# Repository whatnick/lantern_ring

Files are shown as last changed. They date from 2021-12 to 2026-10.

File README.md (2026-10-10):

# Lantern Ring

**One ring to rule them all, in the light bind them**

## v2 physical hardware

[FreeCAD v2 twist-lock hardware](hardware/v2.0/ring_3d/README.md) provides a keyed
30-degree bayonet PCB/battery cassette, opposite-face CR2032 pogo contacts,
one insulated ground lead and screw-retained battery access. The compact crown
is 24.9 mm across, with the original 11 mm band width at the crest and a **rounded open-bottom
elastic band**. Hollow 40-degree conical shoulder walls brace the crown onto the
band, as the legacy side plates did. The shank tapers to 6 mm at the open tips
with comfort-fit rounded edges, using 2.5% less material than the unbraced band. The crown nests onto the finger arc; its LED-inclusive profile
is **11.42 mm above the finger**. A
[same-scale legacy comparison](hardware/v2.0/ring_3d/generated/legacy-comparison.png)
documents the remaining height/diameter difference. Editable CAD and printable
files are included.
Battery replacement needs no soldering; the direct positive pogo and ground
lead still need three permanent joints. This is an unprinted, electrically unqualified prototype for the
mono-colour PCB, not a certified battery-powered product.
The [elastic-fit study](hardware/v2.0/ring_3d/generated/flex-fit.png) illustrates
a 1 mm expansion target, not a qualified size range; PA12 spring-back, creep
and comfortable fit still require physical testing.

### v2 CAD renders

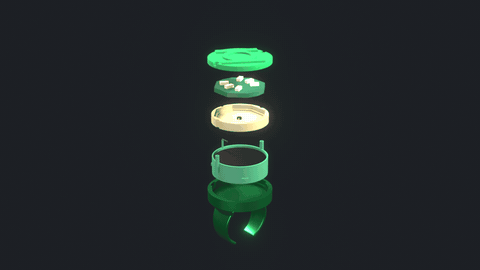
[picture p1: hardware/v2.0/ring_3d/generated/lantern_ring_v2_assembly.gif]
Lantern Ring v2 assembly animation: the exploded cassette drops in under the Green Lantern crown, twist-locks and the LEDs light the crown


Blender 5 assembly animation ([MP4](hardware/v2.0/ring_3d/generated/lantern_ring_v2_assembly.mp4)).

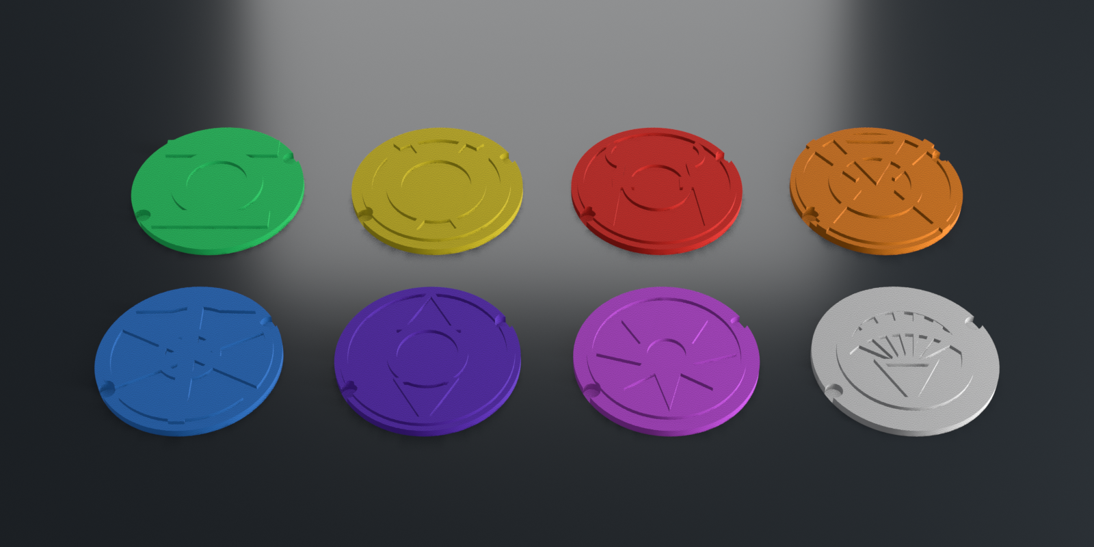
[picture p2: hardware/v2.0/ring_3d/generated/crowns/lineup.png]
Low-profile Lantern Corps crowns: will, fear, rage, avarice, hope, compassion, love and life logos on translucent top pieces


Low-profile [Lantern Corps crowns](hardware/v2.0/ring_3d/README.md#lantern-corps-crowns-low-profile-top-piece):
swappable translucent top pieces that sit 2.3 mm above the PCB (the v1 emblem stood 6.5 mm).

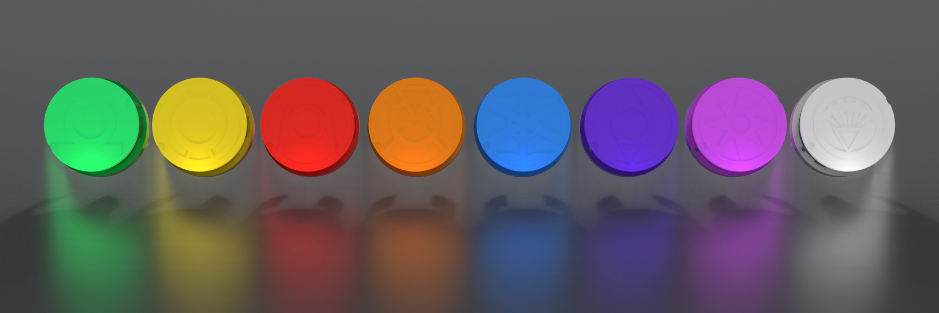
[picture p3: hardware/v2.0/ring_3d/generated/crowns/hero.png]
All eight Lantern Corps rings on their side on a steel surface, glowing caps facing the viewer


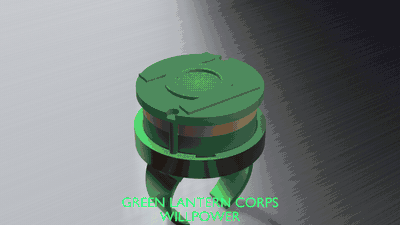
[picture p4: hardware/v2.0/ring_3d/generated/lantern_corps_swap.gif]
Crown swap animation: each Lantern Corps crown is swapped in and the ring relights in that corps colour


Crown swap animation ([MP4](hardware/v2.0/ring_3d/generated/lantern_corps_swap.mp4)),
with each crown and LED colour representing a different Corps.

| Assembled: low crown, braced open tapered band | Exploded: bayonet cassette and pogo stack |
| --- | --- |
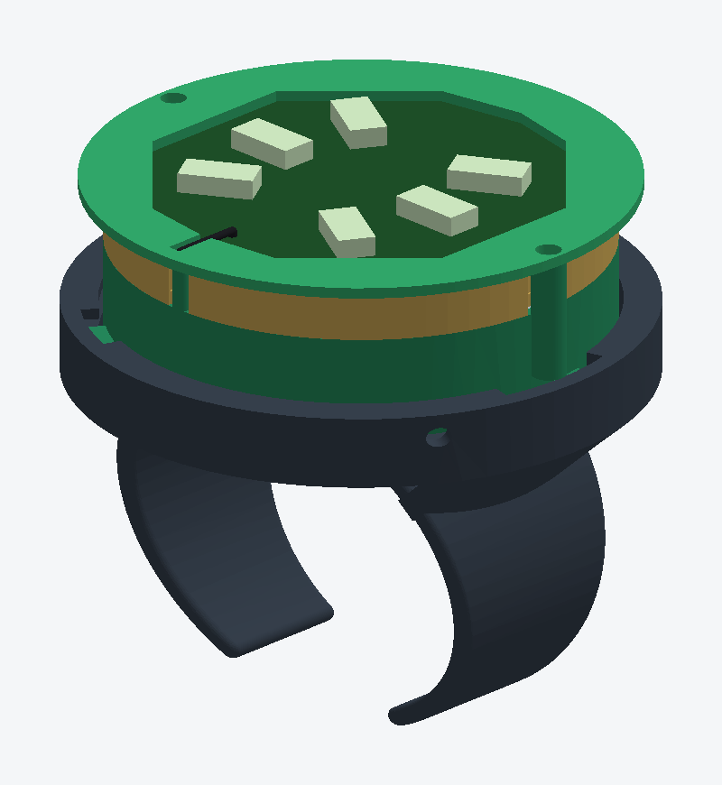
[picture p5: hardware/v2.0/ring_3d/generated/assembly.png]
Lantern Ring v2 assembled CAD with the crown nested on the finger arc and a 60-degree open-bottom band
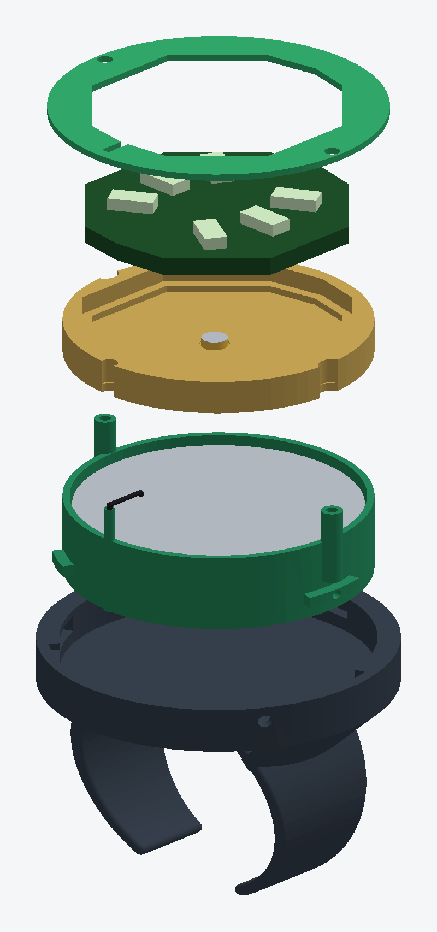
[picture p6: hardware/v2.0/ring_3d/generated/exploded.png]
Lantern Ring v2 exploded CAD showing ring base, CR2032, pogo pins, PCB carrier and bezel
|  |  |

| Same-scale legacy comparison | Open-band elastic-fit screen (unqualified) |
| --- | --- |
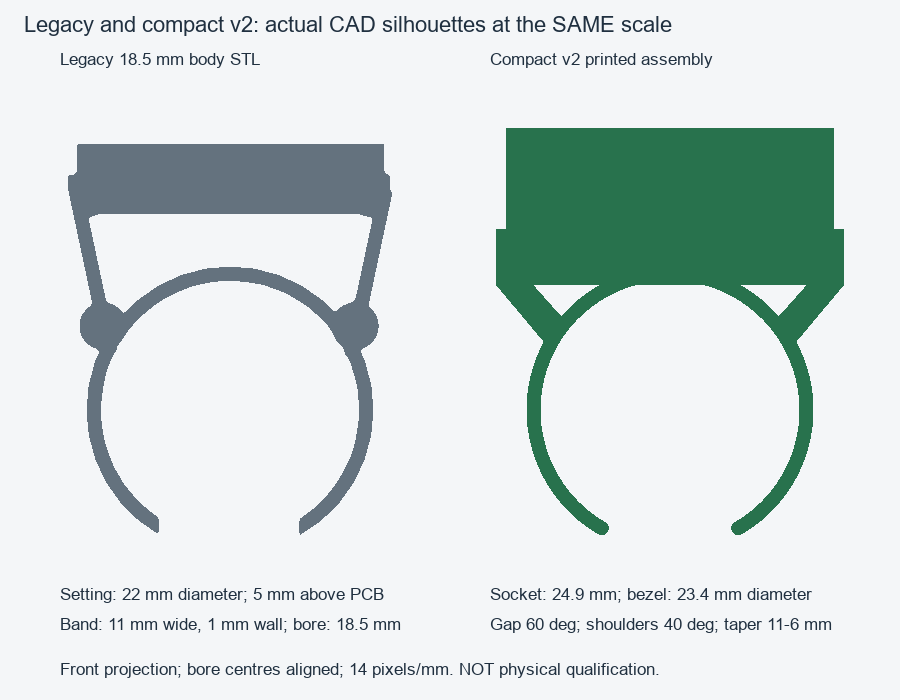
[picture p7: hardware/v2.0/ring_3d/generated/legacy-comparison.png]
Same-scale comparison of the v2 ring against the measured legacy ring
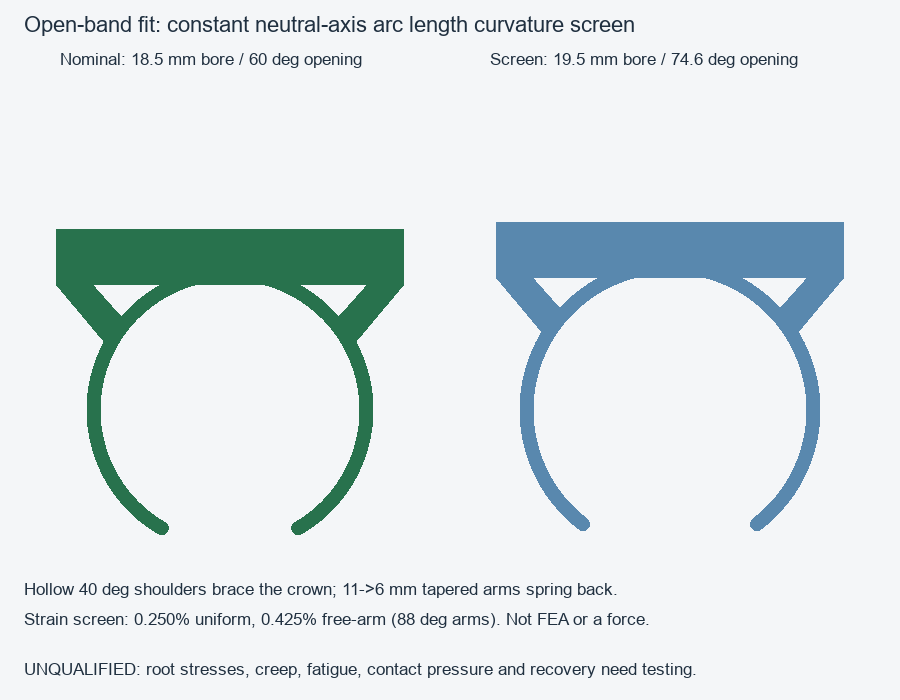
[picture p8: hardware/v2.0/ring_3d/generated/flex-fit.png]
Open-band curvature study from 18.5 mm to 19.5 mm bore
|  |  |

[Repository baseline review](docs/design/repository-review.md) distinguishes the
existing board variants and unfinished experiments.

[Contact and metal-body roadmap](docs/design/contact-roadmap/README.md) explores
copper-tape pressure contacts, replaceable plated springs and an electrically
isolated metal shell, with progressive local renders and prepared Nano Banana
prompts. These concepts do not replace the current manufacturing CAD.

[IR ring programming clip](hardware/v2.0/ring_ir_prog_clip/README.md) is a
solder-free pogo-pin ISP clip for the ATtiny85 `ring_pcb_IR`. It is a probe,
anvil and fence PCB set for an Adafruit 5434-style hinged clip kit. Its pin
spacing comes from the IR board's rear test pads, and it has a standard AVR
ISP-6 header. It passes KiCad ERC/DRC and a FreeCAD virtual fit against
estimated clip dimensions. It has not yet been built or measured.

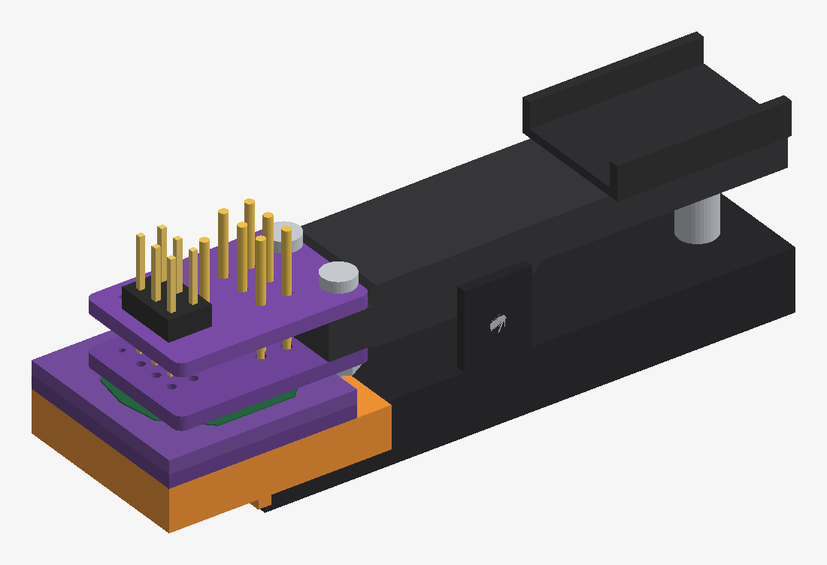
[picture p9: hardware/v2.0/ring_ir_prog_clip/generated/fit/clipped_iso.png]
IR programming clip, virtual FreeCAD fit


Engineering source references and regeneration instructions are in
[development.md](development.md).
| 1. Serviceable pogo | 2. Copper pressure | 3. Plated springs | 4. Floating metal |
| --- | --- | --- | --- |
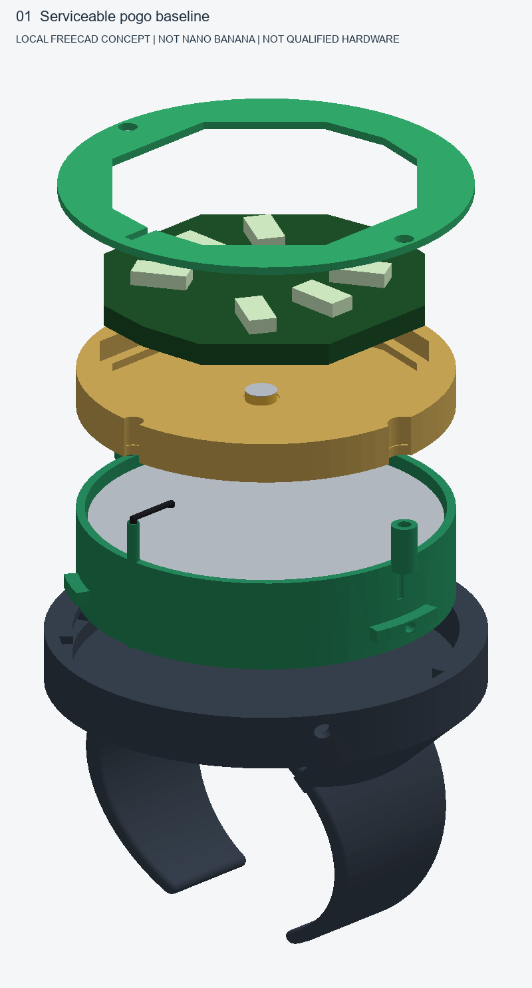
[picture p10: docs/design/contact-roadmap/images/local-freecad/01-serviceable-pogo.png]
Baseline serviceable pogo assembly
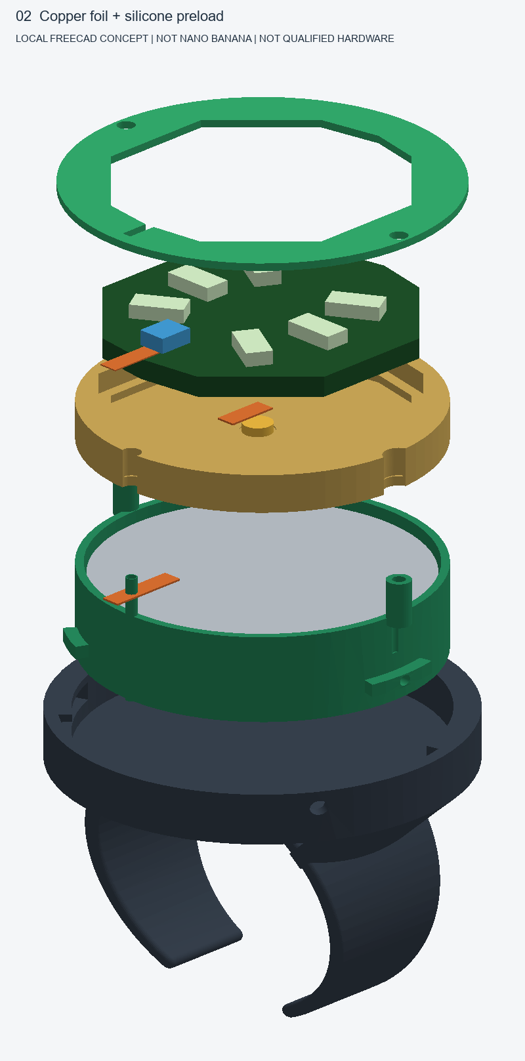
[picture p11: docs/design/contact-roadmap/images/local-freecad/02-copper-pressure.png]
Copper foil and silicone pressure-contact concept
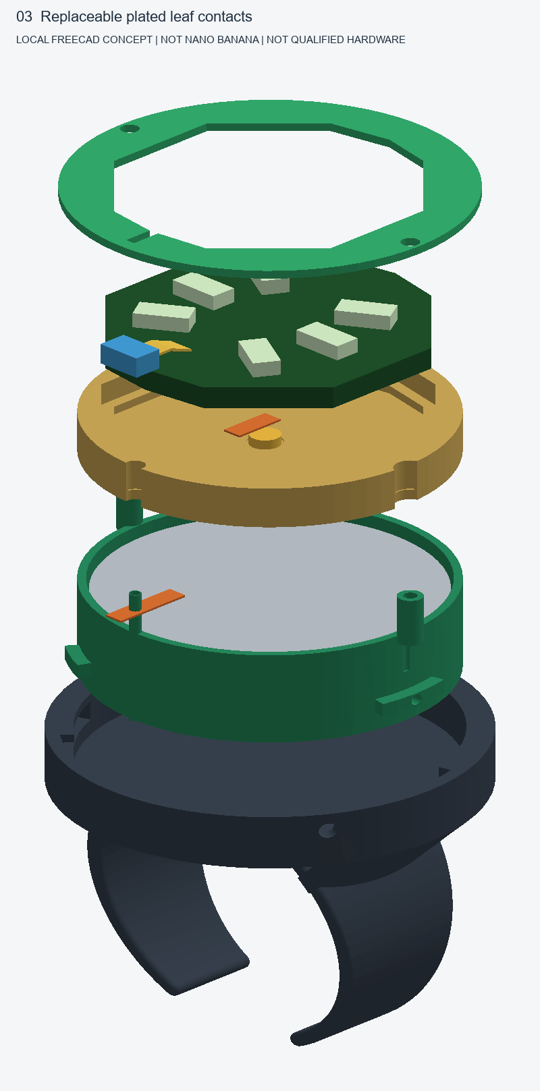
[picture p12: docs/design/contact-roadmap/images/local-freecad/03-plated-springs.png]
Plated spring cartridge concept
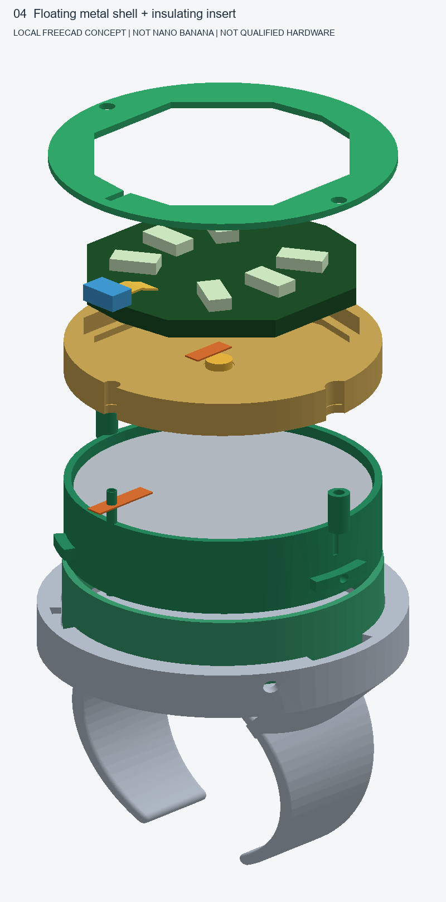
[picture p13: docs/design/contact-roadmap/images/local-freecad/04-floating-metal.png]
Floating metal ring body with polymer insert
|  |  |  |  |

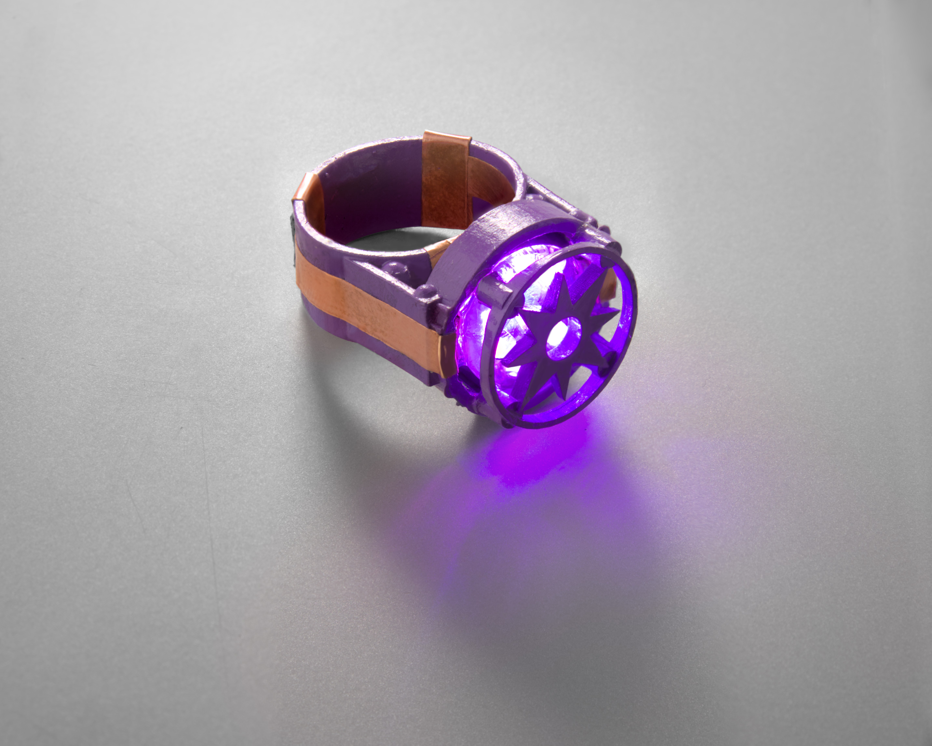
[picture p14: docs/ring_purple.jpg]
Purple Ring

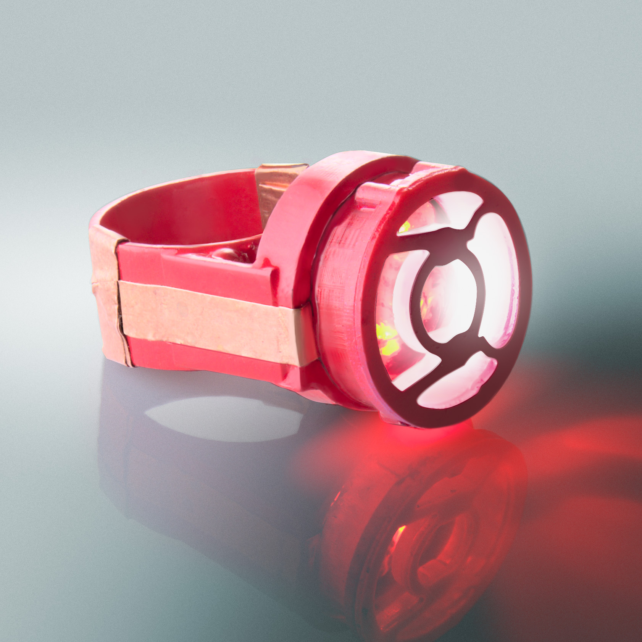
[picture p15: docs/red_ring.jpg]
Red Ring

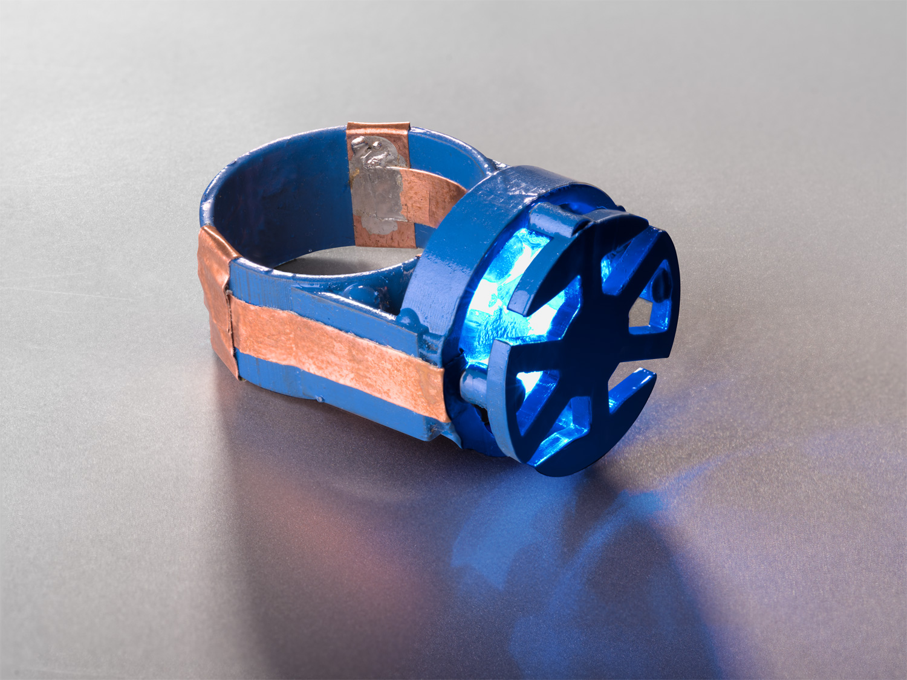
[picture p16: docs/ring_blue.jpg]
Blue Ring


Available on :
- [Tindie](https://www.tindie.com/products/whatnick/lantern-rings/)
- [Etsy](https://www.etsy.com/au/listing/1365896916/lantern-corps-cosplay-ring-with)
- [PCBWay]
- [OSHPark]
- [Aisler](https://aisler.net/p/UOBXJDJP)
- [Shapeway](https://www.shapeways.com/shops/whatnick)
  - [Ring body](https://www.shapeways.com/product/PLQWLUV6V/lantern-ring-body?optionId=251926151&li=shop-inventory)
  - [Green Lantern Logo](https://www.shapeways.com/product/PLQWLUV6V/lantern-ring-body?optionId=251926155&li=shop-inventory)
  - [Yellow Lantern Logo](https://www.shapeways.com/product/87AK6SYQN/yellow-fear-lanterns-logo-from-dc-universe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)
  - [Blue Lantern Logo](https://www.shapeways.com/product/LDGX3RYWW/hope-lanterns-logo-from-dc-universe?optionId=253809602&li=shops)
  - [Indigo Lantern Logo](https://www.shapeways.com/product/RX6YYCM8E/indigo-empathy-logo-from-dc-universe?optionId=253810127&li=shops)
  - [Violet Lantern Logo](https://www.shapeways.com/product/Q4ZM3RG58/purple-love-lanterns-logo?optionId=253810197&li=shops)
  - [Red Lantern Logo](https://www.shapeways.com/product/2T2WC596J/red-rage-lanterns-logo?optionId=253810042&li=shops)
  - [Orange Lantern Logo](https://www.shapeways.com/product/XHF33N3QN/orange-avarice-lanterns-logo?optionId=253810121&li=shops)
  - [Black Lantern Logo](https://www.shapeways.com/product/NEF64B7SB/lantern-ring-life-and-death)
  - [White Lantern Logo](https://www.shapeways.com/product/NEF64B7SB/lantern-ring-life-and-death)
  - [Black MTG Logo](https://www.shapeways.com/product/NJ25J3LPM/magic-the-gathering-black-mana-logo?optionId=253809132)

[LED Colours and quantum physics](https://www.forbes.com/sites/chadorzel/2019/07/01/the-mostly-quantum-physics-of-making-colors/?sh=2ce5846e3953) are inextricably linked.
After watching a temperature based LED colour changing demo at questacon, an idea started forming in my head for using a similar idea with LED's of different colours and seeing how they
react spectrally with temperature.

I have also always been a Green Lantern nerd and I have been making lantern rings since 2010. You will probably find some of them in the wild in Hobart among the clientele of various
pubs and nightclubs. This is a more serious attempt at making a piece of electronic jewellery, cosplay prop and nerdy onanism all rolled into one.

## Licence

[OSHW TAPR](https://tapr.org/the-tapr-open-hardware-license/)

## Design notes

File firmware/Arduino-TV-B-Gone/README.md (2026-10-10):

# Description:  
This code is the TV-B-Gone library ported to run on the Attiny85 back but using the Arduino IDE.  

# README.md update history:  
Readme Last Updated: 22 Oct. 2016  
By Gabriel Staples, http://www.ElectricRCAircraftGuy.com  
-My contact info is available by clicking the "Contact Me" tab at the top of my website.  

# Current Code Version & History:  
See [development.md](development.md) for the source-file history and build notes.

Semver (http://semver.org/) VERSION HISTORY (newest on top):  
(date format: yyyymmdd; ex: 20161022 is 22 Oct. 2016)  
 - 20161022 - v1.3 - Semver versioning implemented; various code updates, clarifications, & comment additions, and changes to fix PROGMEM incompatibilities so it will now compile with latest versions of gcc compiler; also improved blink indicator routines & added the ability to stop the code-sending sequence once it has begun; by Gabriel Staples (http://www.ElectricRCAircraftGuy.com)  
 - 20101023 - v1.2 - Latest version posted by Ken Shirriff on his website here (http://www.righto.com/2010/11/improved-arduino-tv-b-gone.html) (direct download link here: http://arcfn.com/files/arduino-tv-b-gone-1.2.zip)  
 - 20101018 - v1.2 - Universality for EU (European Union) & NA (North America) added by Mitch Altman; sleep mode added by ka1kjz  
 - 2010____ - v1.2 - code ported to Arduino; by Ken Shirriff  
 - 20090816 - v1.2 - for ATtiny85v, by Mitch Altman & Limor Fried (https://www.adafruit.com/), w/some code by Kevin Timmerman & Damien Good  

# Description:  
This code is the TV-B-Gone library ported to run on the Arduino.  

# Background:
See [development.md](development.md) for source-file notes and build details.

Updated code to fix PROGMEM incompatiblities--now works with latest versions of gcc compiler & Arduino IDE
-with other improvements also
By Gabriel Staples (http://www.ElectricRCAircraftGuy.com)

This port to Arduino is by Ken Shirriff.  
For background details on the Arduino port, how to build it, and how to use it, see:  
 * http://www.arcfn.com/2009/12/tv-b-gone-for-arduino.html and here:
 * http://www.righto.com/2010/11/improved-arduino-tv-b-gone.html (newer)

For information on the original TV-B-Gone see:  
http://www.tvbgone.com/. Mitch Altman is the inventor of the original TV-B-Gone.    

The original code is:  
TV-B-Gone Firmware version 1.2  
 for use with ATtiny85v and v1.2 hardware  
 (c) Mitch Altman + Limor Fried 2009  
 Last edits, August 16 2009  

Added universality for EU or NA, and Sleep mode to Ken's Arduino port.  
 -- Mitch Altman  18-Oct-2010  
Thanks to ka1kjz for the code for adding Sleep  
    <http://www.ka1kjz.com/561/adding-sleep-to-tv-b-gone-code/>  

With some code from:  
Kevin Timmerman & Damien Good 7-Dec-07  

# License:  
Distributed under Creative Commons 2.5 -- Attribution & Share Alike  

# CIRCUIT:  
The hardware for this project uses an Arduino:  
 * Connect an IR LED to pin 3 (IRLED).  
 * Connect a visible LED to the pin 13 (or use the built-in LED in many Arduinos).  
 * Connect a push-button between pin 2 (TRIGGER) and ground.  
 * Pin 5 (REGIONSWITCH) must be left floating for North America, or wire it to ground to have it output European codes.  

# User Manual:  
## Background Settings:  
 * The TV-B-Gone for Arduino can use either the EU (European Union) or the NA (North America) database of POWER CODES  
 * EU is for Europe, Middle East, Australia, New Zealand, and some countries in Africa and South America  
 * NA is for North America, Asia, and the rest of the world not covered by EU  
 * Let pin 5 float for NA codes, or wire it to ground to have it send EU codes  
 * Serial debugging output and timing adjustments are configured in the firmware.
  * Fine-tune if necessary  
  * We'd love to have you add more! Just be careful NOT to duplicate codes please!  
  
## Use:  
 * When the device is first powered on, it will quick-flash (30ms on-time followed by 250ms off-time) 3 times if set to output NA (North America) codes, or 6 times for EU (European Union) codes.
 * Once on, the device will enter sleep mode, where it will remain until a button press occurs on the TRIGGER pin, at which point it will wake up and send all of its power codes for the region set according to the state of the REGIONSWITCH pin.  
 * Once you press the TRIGGER button (on pin 2), all power codes will be sent sequentially, one after the other. Note that the trigger button debouncing is done in a very primitive fashion, so quick button presses and releases (<500ms) may work best. If you just hold down the button, the code sending sequence will be continually started, stopped, and started again, since a button press during code sending is used to stop the sending sequence.  
 * After each individual IR power code is sent, a quick flash will occur on the visible LED (30ms on-time) to indicate a code was just sent. Therefore, as the codes are sent, you will see the visible LED flash repeatedly.  
 * Once all codes have been sent (which takes around 60 sec or so), a ~1.3 sec pause followed by 8 quick flashes will occur to indicate that all power codes have been sent. Then, the device will go back into sleep mode until another TRIGGER button press occurs.  
 * Between individual power codes, the TRIGGER button is read one time. If it is read as pressed (LOW), the code sending sequence will be stopped early. This will be indicated by a ~705ms delay followed by 4 quick-flashes, followed by another ~1.3 sec delay to give you time to release the button.  
  * NB: since the TRIGGER button is only read between individual codes, rather than continuously, you may need to hold down the button for a half-second to second or so for it to be read properly as pressed. Once the delay and 4 quick-flashes begin, you can release the button, and the power codes will be stopped. The device will enter back into sleep mode. Press the button again to begin the code sequence again from the beginning.  
  * NB: If you keep holding the button, however, this will be read as a new button-press in the main loop and the sequence will be restarted. Therefore, continually holding the button will just keep starting and stopping and starting again the sending sequence, repeatedly.

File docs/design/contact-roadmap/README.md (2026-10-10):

# Contact and metal-body design roadmap

**Status: ideation, not a revised manufacturing release.** The illustrations
now reference the [compact v2 CAD](../../../hardware/v2.0/ring_3d/README.md):
24.9 mm socket, 23.4 mm bezel, 11 mm-wide open-bottom PA12 band, a nested crown
with an 11.42 mm LED-inclusive above-finger profile, short 0965 SMT pogo pins and a direct
rear-VCC solder connection. They do not reinstate the oversized 36.4 mm crown.
This roadmap explores eliminating the permanent PCB connections while
retaining opposite-face CR2032 pogo contacts and the removable bayonet cassette.
An outer ring body can be metal; the battery/contact insert still needs insulation.
The baseline's split arms use material spring-back; their
[1 mm expansion study](../../../hardware/v2.0/ring_3d/generated/flex-fit.png)
is not a validated fit range. A metal concept must preserve the open-bottom
intent but re-engineer arm thickness, spring force, fatigue and comfort for
its actual alloy/process, not copy the PA12 section.

**Nano Banana generation is blocked:** no authenticated image-generation
service is available, so no Nano Banana images have been generated. The four
renders below were generated **locally with FreeCAD**. They are explicitly
labelled alternatives, not evidence that Nano Banana ran. Development and
image-generation details are in [development.md](development.md).

## Progressive concepts

| Stage | Contact idea | Evidence currently available | Next gate |
| --- | --- | --- | --- |
| 01 | Existing wire loom plus battery pogo pins | Existing native CAD, local exploded illustration | Print/bench qualify the baseline |
| 02 | Copper foil lands, silicone preload, mechanically captured terminations | Local concept overlay and authored contact section | Separate pad-contact coupons and short-circuit checks |
| 03 | Replaceable plated leaf-contact cartridge | Local concept overlay | Engineer force, stops, wiping motion, plating and fatigue |
| 04 | Metal band/socket with floating shell and insulated cassette | Local material/liner concept overlay | Design actual metal process, insulation and isolated fasteners |
| 05 | Contact-path and isolation section | Authored schematic; Nano Banana section prompt prepared | Verify both electrical paths and every possible short path |

### 01 - Serviceable baseline

Baseline serviceable assembly

This is the control design: the PCB rides in a profiled contact deck; a wide-key
three-lug cassette turns 30 degrees counterclockwise and is retained with an
anti-unlock screw. Two battery pogo pins connect through a soldered insulated
ground lead, with the positive pin base soldered directly to rear VCC. Battery
changes need no soldering. The exploded picture is explanatory,
not the literal removal sequence: remove bezel/PCB/deck before lifting the cell.

### 02 - Copper tape and compression pads

Copper foil and silicone pressure-contact concept

Orange lands illustrate copper foil; blue blocks illustrate compliant backing.
Two **separate** PCB contacts replace the PCB wire joints:

- Rear central **VCC**: a copper land faces upward under the exposed pad, with
  compliant backing supported by the insulating deck.
- Front **TP1 `/GND`**: a separate foil land faces downward onto the edge pad,
  with compliant backing supported by the bezel and an insulated perimeter route.

The retaining stack supplies controlled normal pressure. A small seating wipe
may help contact cleanliness; friction alone is not the retention or preload
mechanism. Copper foil is not a spring, and the adhesive side must not be the
pad-contact face. Conductive adhesive at an overlap is not an assumed durable
joint. Capture each continuous strip mechanically, protect cut edges, prevent
foil lift/creep, and keep it away from LEDs and unrelated exposed copper.

The silicone thickness, compression, compression set and final force are **not
specified yet**. The small pad footprint limits contact-placement tolerance.
Prototype removable coupons against the actual board finish before cutting new
carrier tooling. Bare copper oxide, sweat and repeated sliding are reasons to
treat tape as an experiment, not the final wearable contact material.

The conductor-to-pogo interface must also be solved: a captive clamp/spring
socket would replace the SMT base solder joint, but loose tape touching a
pin base is not an acceptable terminal. Four pressure/clamp interfaces are
not automatically more reliable than four permanent solder joints.

### 03 - Replaceable plated spring contacts

Plated spring cartridge concept

Gold-coloured leaf profiles replace the tape contact lands; blue blocks show
mechanical root capture. Separate phosphor-bronze contacts can provide their own
elastic preload, with rounded contact points, designed travel and overtravel
stops. Keep the VCC and ground leaves distinct and provide a replaceable
insulating cartridge rather than springing the PCB itself.

Select alloy temper, thickness, root radius, plating and force against the actual
PCB pad finish. A plated contact rubbing an unsuitable pad finish can still wear
through or become intermittent; "gold coloured" in a render is not a plating
specification. The existing KiCad pads have not been enlarged or changed to hard
gold contact lands. Decide whether a future PCB revision needs larger, same-side
power/ground contact lands before claiming a universal drop-in interface.

### 04 - Metal body, insulated electrical module

Floating metal ring body with polymer insert

The silver shell represents stainless steel or titanium as possible structural/
decorative materials, not selected machining or casting specifications. The
green sleeve shows the intention to keep the electronic cassette isolated.
The contact leaves themselves are conductive metal; they remain separate from
the worn shell.

**Do not manufacture the current polymer RingBase STEP in metal as a direct
material swap.** The local illustration reuses the silhouette and adds a liner
overlay; that liner is not fitted into a redesigned bayonet clearance stack.
Wall thickness, tool access, undercut tracks, fastener threads, finish, mass and
liner retention all need a metal-specific CAD revision.

| Metal configuration | Decision |
| --- | --- |
| Floating metal band/socket + continuous polymer liner + two independent contacts | Preferred development direction: metal carries mechanical loads, not battery current |
| Metal body used as ground return | Deferred research option, not implemented: one conductor may be saved, but positive-cell-case contact, sweat, galvanic corrosion, skin exposure and fault paths become harder to control |
| One-piece metal body used for both poles | Not possible without electrically separated conductive regions; do not bridge VCC and ground |

A metal-body design must include:

- Continuous electrical isolation around the battery **positive case/rim**,
  negative contact, both PCB contacts, PCB edges and every termination.
- Insulating sleeves/washers where screws could reach circuitry, with retained
  insulation that cannot shift when the cassette is serviced.
- A raised insulating rim and clearances that survive wear, impact, debris and
  sweat. Paint, anodizing and tape adhesive are not the sole insulation barrier.
- Accessible contact cartridges, anti-unlock retention, deburred skin-facing
  surfaces and a process/finish appropriate for skin contact.

No minimum clearance, liner thickness, metal alloy or skin compatibility is
qualified here. If metal is intentionally connected to a net in a later study,
document that choice explicitly and reassess every short/fault path; do not
silently treat a conductive shell as "ground".

### 05 - Contact topology and insulation

Authored pressure-contact and metal-isolation diagram

This schematic is manually authored, not an AI image or a dimensioned CAD
section. It shows the **opposite preload directions** needed by the existing
board: upward onto rear VCC, downward onto front TP1 ground. The illustrative
leaf/foil shapes in the local exploded renders have intentional visual gaps;
they are not assembled contact-force or continuity simulations. Some path
segments are omitted to keep the images readable. **The schematic and written
net map, not the visual proximity of surfaces, define the intended circuits.**

## Image review

Any generated concept image must be checked for electrical shorts, correct
cell polarity, shell isolation, contact preload and service access. AI imagery
is not dimensional evidence and must not be used to select dimensions or prove
compliance. The current concept renders are not manufacturing geometry.
Development, prompt and provenance details are in [development.md](development.md).

## Prototype gates before promoting any concept into v2 CAD

1. Use separate contact coupons to measure preload, assembly tolerance and
   serviceability. Establish suitable contact-force limits without bending PCB
   edges or overstressing silicone/leaves; do not copy the battery pogo's force
   specification onto PCB leaf contacts.
2. With no cell fitted, verify each intended contact path and isolation between
   VCC, ground and the floating shell. Check terminal clamps, screw paths and
   contact motion through the complete service/lock range.
3. With a current-limited source and representative load, measure voltage drop
   and interruptions while twisting, tapping and moving the assembly. Define
   resistance and transient limits from the LED circuit budget before testing.
4. Trial repeated insertion, battery replacement, contamination/sweat exposure,
   foil/adhesive creep, leaf fatigue, liner wear, drop and accidental countertwist.
   Recheck isolation and loaded contact performance after each exposure.
5. Resolve the mono board's current-limiting and reverse-insertion risks before
   wearable use. Never solder to or charge a primary CR2032. Screw retention is
   not a claim of battery-compartment certification; keep this adult prototype
   away from children.

Once those gates pass, update parameterised engineering CAD, PCB contact lands
if needed, contact BOM and assembly instructions, and run the native/STEP/STL
and motion checks again. Until then the shipped v2 CAD remains the baseline.

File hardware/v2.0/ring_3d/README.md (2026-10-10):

# Lantern Ring v2: keyed twist-lock hardware

**Prototype, not a physically qualified product.** This design replaces the
monolithic v1 assembly with a removable PCB/battery cassette. It drops in, turns
30 degrees counterclockwise as viewed from above, and locks under three bayonet shelves.
One lug is wider to enforce orientation. The PCB sits in a profiled pocket in the
contact deck; **turn the cassette/bezel, never the PCB**.

Assembled CAD
Exploded CAD

Assembly animation

[Assembly animation MP4](generated/lantern_ring_v2_assembly.mp4): the exploded
stack drops into the carrier, the cassette inserts and twist-locks 30 degrees
under the Green Lantern (willpower) crown, and the LEDs light the crown lens.

Same-scale comparison with the legacy ring

Open-band elastic-fit curvature study

The [contact and metal-body roadmap](../../../docs/design/contact-roadmap/README.md)
explores solderless PCB pressure contacts and a floating metal shell with an
insulating cassette. Those renders are concepts, not replacement manufacturing
geometry or qualified electrical interfaces.

## Files and compatibility

The project includes an editable FreeCAD assembly, STEP reference geometry and
printable STL files. See [development.md](development.md) for source references
and regeneration instructions.

The supported board is the **v2 mono-colour PCB only**:
17.78 x 19.05 mm, 1.6 mm thick, with a ten-vertex asymmetric outline. This is not
the v1 17.78 mm octagon. The generator reads actual Edge.Cuts, pad nets and the
rear mask opening, rather than using a library bounding box that includes the
outline stroke. IR, v1 multi-colour and the unfinished DotStar board need their
own measured contact decks; they are not drop-in electrically compatible.

Default dimensions: **18.5 mm unloaded finger bore, 11 mm band width, 24.9 mm
maximum crown diameter and 11.2204 mm printed crown height above Z=0**.
The LEDs extend to Z=11.7204. The bore apex is raised to Z=0.3, so the true
**LED-inclusive profile above the finger is 11.4204 mm**, versus 12.7204 mm
for the previous closed-band design. Removing surplus negative-contact clearance
and reducing the bezel from 1.2 to 0.6 mm lowers the actual crown; the image
has not just been repositioned or rescaled.
The upper bezel is 23.4 mm across. These replace the oversized 36.4 mm diameter /
22.4 mm stack; neither PCB nor cell has been scaled.
Legacy 15.5/16.5/18.5/19.5 mm bore sizes can be regenerated; the 15.5/16.5 mm
bores need a reduced expansion target to stay within the free-arm strain screen.

### Measured legacy envelope and remaining difference

The legacy ring setting has an 11 mm outer radius and is 5 mm high above the PCB
datum; its 18.5 mm band has a 9.25 mm bore radius, 10.25 mm outer radius and
11 mm width. The compact band restores that **1 mm wall**, too.
The legacy 18.5 mm body STL is approximately 23.14 mm wide and 27.90 mm high.
README photographs corroborate the shallow crown/broad-band proportions, but
are not calibrated rulers. The generator measures these native objects and
records their source hashes; the comparison uses the real legacy mesh and new
printed solids at the **same scale**, with finger-bore centres aligned.

| Measured default 18.5 mm body | Legacy | Compact v2 |
| --- | ---: | ---: |
| Setting / upper bezel diameter | 22 mm | 23.4 mm |
| Maximum body width | ~23.14 mm | 24.9 mm |
| Overall printed-body height | ~27.90 mm | ~29.11 mm |
| Band width / wall | 11 / 1 mm | 11 tapering to 6 / 1 mm |
| Crown-to-band bracing | ~12-17 deg near-vertical plates, hollow | 40 deg hollow conical shoulders |

This is **not an exact 22 mm replacement**: the keyed polymer tracks need a
24.9 mm socket, 2.9 mm wider than the historical setting. The face lip is now
2.2 mm above the PCB underside, rather than 5 mm. Two spring contacts still add
4.4704 mm of working axial height around the unscaled 3.2 mm cell, so the
complete enclosure remains taller than the old direct-contact body. The old
5 mm face height and the new 11.2204 mm base-to-top stack have different datums
and must not be presented as equivalent measurements. Matching the complete
old envelope would require a different contact architecture, not uniform scaling.

### Open-bottom material-spring fit

The closed loop is replaced by **two continuous 1 mm-thick PA12 arms**, with a
60-degree bottom opening and 0.5 mm-radius end caps across the band width.
The unloaded tip gap is 8.75 mm. The top sits low on the circular finger
arc: the raised bore cuts into the crown underside, while a **continuous 0.5 mm
floor separates skin from the contact well**. Only the finger band is open; the
battery compartment is not.

### Braced shoulders and tapered comfort-fit band

Like the legacy body's slanted side plates, **hollow 1 mm conical shoulder walls**
brace the 24.9 mm crown overhang onto the band. Each wall leaves the crown
underside at its 12.45 mm rim and descends **40 degrees from the crown axis**
(validated 30-45 degrees), meeting the band 4.09 mm below the
crown, 61.7 degrees from its crest. The walls lean less steeply than the old
~12-17-degree plates, so they meet the band higher, keeping long free spring
arms. At 50 degrees from horizontal, they print without supports. The
triangular pockets between walls and band remain open front-to-back, saving
material and allowing powder removal.

Following common ring-profile practice (see
[MOH London ring profiles](https://www.mohlondon.com/guidance/design-basics/ring-profiles)),
the shank tapers on its lower side: one plane per side narrows the band from the
legacy **11 mm crest to 6 mm at the open tips**. The long edges are rounded to
a **0.35 mm comfort-fit radius**.
The narrower, lower arms also make bending stress more uniform along the spring.
Net RingBase volume falls from 1194.3 to 1164.8 mm^3 (-2.5%), despite the
added bracing. OCC produces C0-continuity BSpline fillet faces; the validator
accepts only those flags, while every other BOP error, watertight-mesh check
and STEP round trip remains strict.

Elastic bending of these free arms supplies spring-back and fit preload; there
is no additional metal spring or adjustment screw. Start with a nominal bore
close to the measured finger size. A slightly smaller unloaded bore can supply
preload only after fit/force testing; do not force an undersized print onto a
finger or use elastic travel to compensate for a wrong ring size.

The 1.0 mm expansion is a **screening target**, not a certified 18.5-19.5 mm
size range. The illustration preserves neutral-axis arc length while widening
the opening to about 74.6 degrees. The simple curvature estimate
strain = wall/2 * (1/R - 1/(R + expansion/2)), with R = (bore + wall)/2,
gives approximately **0.250%** outer-fibre strain. The shoulders stiffen the
root, so a second screen assumes only the 88.3-degree free arm takes the same
tip rotation: 0.250% x 150 / 88.3 = **0.425% free-arm strain**. Both omit root stress
concentration, contact loads, nonlinear geometry, residual print stresses,
anisotropy, creep and fatigue. It is not FEA or a spring-force prediction.
The 0.5% screen ceiling is a conservative design input, **not a published
PA12 cyclic allowable**.

Use a controlled ductile PA12 process for this spring geometry. The
[EOS PA 2200 material reference](https://store.eos.info/products/pa-2200-polyamide-12)
is a material-selection starting point, not a guarantee of elastic recovery.
Print an actual split-band coupon in the intended build orientation and finish,
cycle it on 18.5/19.0/19.5 mm gauges, and measure force, permanent set and recovery
before a worn trial. Repeat after warm/humid conditioning and sustained
deflection. Stop if the roots whiten/crack, the band takes a set, or fit is
painful/restricts circulation. No claimed skin compatibility or wear safety.
Do not copy the same thickness into resin, PLA or a metal body: their spring
stiffness and failure modes differ. Metal needs separately engineered arms.

## Development

The assembly is parametric and its source, validation, test and regeneration
workflow are documented in [development.md](development.md).

### Assembly animation (Blender 5)

The animation uses the Will (Green Lantern) crown in place of the plain bezel.
Colours are illustrative: the lower body is shown as emerald metal and the
crown as frosted translucent plastic. Intermediate scene files and frames are development artifacts and are not
distributed.

### Lantern Corps crown swap and hero still

Lantern Corps crown swap

[Crown swap MP4](generated/lantern_corps_swap.mp4): on a brushed-steel surface,
each crown lifts off, the light goes dark, the next corps crown drops in and the
LEDs relight in that corps colour, with a caption naming the corps and light.

All eight Lantern Corps rings on their side on steel, caps facing the viewer

Corps ring-body tints are illustrative; only the crowns are generated geometry.

## Lantern Corps crowns (low-profile top piece)

Lantern Corps crown lineup

The v1 emblem stood a 2 mm logo on 5 mm risers: 6.5 mm above the setting.
The replacement **crown** is the validated bezel (same PCB-edge
clamp, M1 x 4 screws and ground-lead relief), a skirt that clears the LEDs by
0.2 mm, a 0.4 mm diffuser lens and a 0.6 mm raised logo. The crown top is
**2.3 mm above the PCB and 1.2 mm above the tallest LED** (12.62 mm profile
above the finger). Each crown is printed in one piece from translucent material
and is swapped by removing the two bezel screws.

Logos are traced from the per-corps sketches in the v1 FreeCAD assembly into
tool-neutral closed even-odd outlines, centred on the ring axis. They are
pre-rotated by the 30-degree lock angle so they read in the v1 orientation once
locked, and clipped to the 23.4 mm bezel.

| Crown | Corps | Light | Volume (mm³) |
| --- | --- | --- | ---: |
| `will` | Green Lantern Corps | willpower | 497 |
| `fear` | Sinestro Corps | fear | 499 |
| `rage` | Red Lantern Corps | rage | 477 |
| `avarice` | Orange Lantern (Agent Orange) | avarice | 509 |
| `hope` | Blue Lantern Corps | hope | 520 |
| `compassion` | Indigo Tribe | compassion | 476 |
| `love` | Star Sapphires | love | 474 |
| `life` | White / Black Lantern | life and death | 491 |

The STEP crowns are supplied in the cassette insertion frame, and the printable
STLs are oriented **logo face down**: the relief prints first and the lens
bridges it. Their geometry and regeneration workflow are documented in
[development.md](development.md).

**Not printed yet.** Lens light spread, 0.6 mm relief legibility and the 2.2 mm
counterbores that notch the crown rim need a test print.

## Printed parts and purchased parts

| Item | Quantity | Specification |
| --- | ---: | --- |
| RingBase | 1 | Braced, tapered comfort-fit split band and nested keyed bayonet socket |
| Carrier | 1 | Insulated battery well, negative pogo seat, lead channel, lugs, side pillars seated on the RingBase |
| ContactDeck | 1 | Positive pogo seat and actual PCB pocket |
| Bezel | 1 | PCB-edge clamp and open optical window |
| Crown (optional) | 1 | Replaces Bezel: translucent Lantern Corps logo top piece, see [crowns](#lantern-corps-crowns-low-profile-top-piece) |
| Spring contact | 2 | Mill-Max **0965-0-15-20-80-14-11-0**, surface mount ([alternatives](../../../docs/design/pogo-pin-comparison.md)) |
| CR2032 | 1 | Primary 3 V cell, nominal 20 x 3.2 mm |
| Insulated flexible wire | 1 | Fine-stranded wire, **jacket OD <=0.4 mm**, black |
| Bezel screw | 2 | M1 x 4 mm plastic-compatible thread, head OD <=2 mm |
| Anti-unlock screw | 1 | M1 x 2 mm plastic-compatible thread, low-profile head |
| Pin-retaining adhesive | Small amount | Nonconductive, electronics-compatible epoxy |

Use a dimensionally controlled PA12 process for the compact parts, not brittle
decorative resin. The battery well has a 0.5 mm wall and the outer track wall is
0.8 mm: this is **not a drop-in coarse FDM print**. Qualify these small walls,
the 1 mm lugs, 0.6 mm bezel and M1 threads on coupons before printing the ring.
RingBase needs appropriate supports under the crown and track
roofs; its Z=0 STL position is not a promise of support-free printing. The deck
and bezel are naturally base-down. Deburr/smooth skin-facing band edges and all
track mouths. Do not paint contact pockets or functional sliding surfaces.

Nominal clearances: 0.20 mm carrier/socket radial, 0.25 mm PCB per edge,
0.15 mm cell radial, 0.20 mm lug/track axial, 2 degrees at
each lug flank. Measure a first print and calibrate for the printer; do not force
an interference fit against the PCB or battery. Ream small holes as necessary.
The carrier's two side pillars extend down to the RingBase top at the socket
shoulder (Z=4.0 mm) and bear on its annular wall. Keep the pillar bottom and
socket top at the same height when changing the stack.
The 1.75 mm barrel bore must remain smaller than the 1.829 mm flange: do not
drill through the retaining shoulder. Epoxy is required to retain the pins under
spring load; printed shoulders alone do not secure both directions. The upper deck rests
on the carrier shoulder; its two side notches clear the external screw towers.

## Electrical interface and soldering

**CR2032 positive (+) face UP.** Positive case/rim belongs to VCC; the inset
negative face points down. Never rely on the rim as a ground contact.

| Circuit path | Physical connection |
| --- | --- |
| Positive | Downward-facing SMT pogo at CAD (0, +0.381) touches the + top face; its base is soldered directly to the rear exposed VCC circle |
| Negative | Upward-facing lower SMT pogo at CAD (0, 0) touches the centre of the inset - bottom face; black lead joins its base to front **TP1 `/GND`** |

CAD XY origin is KiCad (136.906, 83.185) mm. CAD +Y is KiCad -Y, without
mirroring the board. TP1 is CAD (-0.0254, +7.493). The rear exposed VCC circle
has radius 2.962124 mm; it is **not ground**.

The [manufacturer drawing, page 24](https://www.mill-max.com/sites/default/files/external/assets/2020-04/ultra_low_profile_spring_pins_rev._04.14.20.pdf)
specifies 2.54 mm free height, 0.3048 mm mid-stroke, 0.6096 mm full stroke,
1.626 mm barrel, 1.829 mm base, 0.7112 mm base height and 1.067 mm tip.
There is **no projecting solder tail**. The CAD uses a conservative stepped
external envelope (body height = free height minus full stroke), not internal
pin construction. A 0.05 mm solder land models the direct positive PCB joint.
Both tips are nominally compressed 0.3048 mm. The combined budget is
**+/-0.2524 mm**, allowing 0.0524-0.5572 mm compression.
Supplier dimensions and cell tolerances must be checked again for substitutions.

The pin length allowance is the manufacturer's +/-0.006 inch (+/-0.1524 mm).
The other allowances are **requirements**, not assumed printer or CR2032
capabilities: measure/sort cells to +/-0.05 mm and finish/shim the assembled
contact stack to +/-0.05 mm. Ordinary +/-0.2 mm printing/cell allowances would
lose preload or bottom out these short pins. Do not use a build outside those
measured budgets. The first-build qualification must measure each pin's free
height and both actual compressed gaps.

There is **no soldering to the battery** and no solder work for routine battery
replacement. The compact assembly needs **three permanent joints**: upper SMT
pin to rear VCC, black wire to lower pin base, and black wire to TP1. This removes
the red wire and one joint compared with the previous four-joint loom; it is
not a solderless retrofit to the unmodified PCB.

Start with approximately 35-40 mm black lead, then trim during dry assembly.
Leave 8-10 mm black service slack folded in the 3 mm wide underside
channel so the board/deck can lift for cell replacement. The CAD wire shapes are
nominal jacket-routing envelopes, not bend-radius or service-loop simulations.
Use strain relief on insulated wire, never on plungers. Keep solder, epoxy and
flux off spring tips and out of barrels. Insulate the lower base joint. Nothing conductive may bridge
the cell's negative face to its positive case.

## Assembly and service

1. Dry-fit all four prints without a cell. Check the wide key, insertion,
   counterclockwise turn, end stop and anti-unlock screw alignment.
2. Install the lower pogo upward through the Carrier's underside counterbore;
   seat its flange and bond the barrel/flange without contaminating its travel.
   Solder the upper SMT pin base squarely to the PCB's rear VCC land, then
   lower it into the deck counterbore. Its spring points down. Secure its barrel
   to the deck without loading the solder pad in service. Let adhesive cure fully.
3. Build/fit the black lead, with the battery absent. Connect it to
   front TP1 `/GND` and the lower SMT base. Check continuity from
   each tip to its intended pad and absence of a VCC/GND short.
4. Insert the cell **+ up**, lower the deck into the open carrier, and seat the
   PCB component-side up with TP1 aligned to the ground-wire relief. Keep slack in the underside
   channel and route black through the bezel's ground-pad relief.
5. Fit the bezel and two M1 x 4 screws into the carrier towers; tighten
   gently, without bending the PCB or stripping the plastic. They retain both
   PCB and deck. Check that the leads are not pinched.
6. Align the wide lug with its wide slot, lower the cassette until seated,
   turn counterclockwise 30 degrees, then install the M1 x 2 anti-unlock screw through
   the radial crown hole into the wide lug's pilot. **The screw is mandatory**:
   friction alone is not an anti-rotation latch.

The **cassette** has positive orientation keying (24/14/14-degree lugs), not the
bare PCB: printing clearance can accommodate a 180-degree reversed board in the
profiled pocket. Align TP1 to the bezel relief and verify the contact loom;
do not rely on the PCB outline alone to establish electrical orientation.

To replace the cell, remove the anti-unlock screw, turn the cassette back
30 degrees and lift it out. Remove the two bezel screws, lift the PCB/deck
together with the available wire slack, and lift the old cell from the open
well. Reassemble with a fresh cell; no contact joints are disturbed. The deck
must lift: a 20 mm battery cannot pass through the smaller PCB pocket.

## Validation and release gates

The CAD validation fails on invalid parameter stacks, failed FreeCAD booleans,
unintended assembled interference, non-solid printed parts, or nonwatertight
STLs. It samples axial insertion, the complete twist, both incorrect key
orientations, locked axial withdrawal, cell extraction, and both battery tip
planes. STEP and STL files are re-imported, and FCStd is reopened/recomputed.
It also checks the full-width bottom opening, retained finger-side floor and
the LED-inclusive above-finger height. STEP volume must agree within 0.01 mm^3.
OCC 7.5 STEP curve-on-surface checks
use an explicit 0.00001 mm numerical tolerance; this is not a print allowance.
Validation and release checks are summarized in the development documentation.
Automated checks cover geometry and source provenance; the CI job does not run
FreeCAD itself.

**Still required on the bench:** split-arm force/recovery, root strain, creep/
fatigue and gauge-fit testing; printer fit coupons/full first article; screw
pullout, adhesive retention, lock wear/drop resistance, pin force/travel across
actual cell tolerances, wire-slack service trial, contact resistance under load,
LED current and temperature, and short/reverse-insertion checks with a
current-limited source before inserting a cell. This revision has not been
printed or tested electrically.

The mono PCB has no explicit LED series-current limiter; do not assume battery
internal resistance or the pogo pin's ampere rating makes it safe. Qualify the
chosen LEDs/cell and add an appropriate current-limiting circuit if needed
before wearing or distributing the assembly. The enclosure is not waterproof,
does not charge cells, and provides no automatic reverse-polarity protection.
**Never charge a CR2032**, including with the repository's speculative Qi ideas.
Coin cells are an ingestion hazard: this is an adult prototype, not a toy.
Screw retention is not a claim of compliance with battery-compartment standards.

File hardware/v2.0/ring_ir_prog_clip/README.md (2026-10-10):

# Ring IR programming clip

A solder-free in-system programming (ISP) clip for the
[`ring_pcb_IR`](../ring_pcb_IR) ATtiny85 board. Spring-loaded pogo pins press on
the board's rear test pads, held by a hinged clip like
[Adafruit 5434](https://www.adafruit.com/product/5434) but with pin spacing
matched to the ring. The parts are the jaws, spring and hardware from the
[AliExpress DIY pogo clip kit](https://www.aliexpress.com/item/1005006153573416.html),
with its generic guide PCBs replaced by the boards here.

> **Status: generated, checked in KiCad, and fitted virtually in FreeCAD.**
> ERC and DRC pass with zero violations of any severity. The FreeCAD fit check
> passes against a clip model built from **photo and datasheet estimates**,
> because the seller publishes no drawing. The clip has not been built or
> physically fitted, and it has not programmed a ring. The clip dimensions and
> pogo-pin dimensions are unmeasured.

Clipped prototype, virtual FreeCAD fit

| Probe (pin side up, two stacked) | Probe (ring side) | Anvil (lower jaw) | Fence (locator) |
| --- | --- | --- | --- |
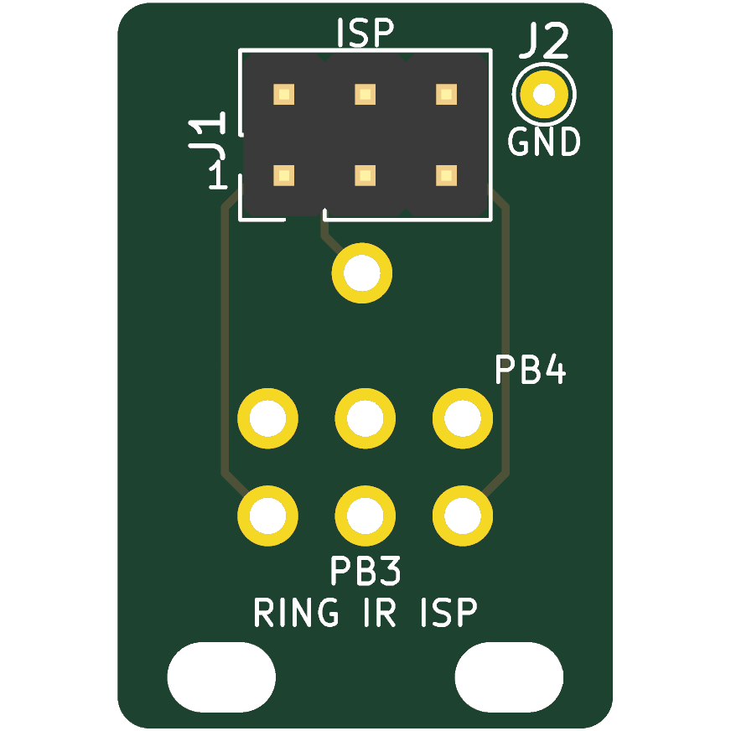
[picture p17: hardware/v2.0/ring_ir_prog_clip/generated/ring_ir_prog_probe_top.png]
Probe top
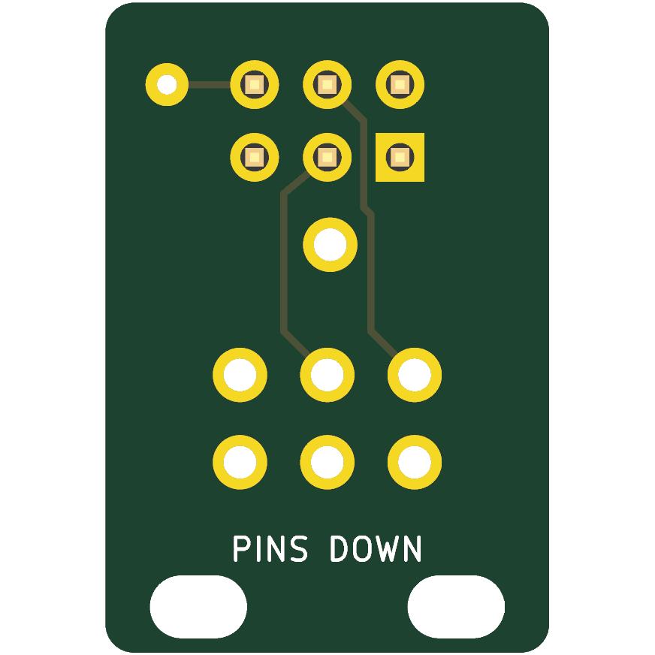
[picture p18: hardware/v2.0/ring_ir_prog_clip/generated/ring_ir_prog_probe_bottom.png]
Probe bottom
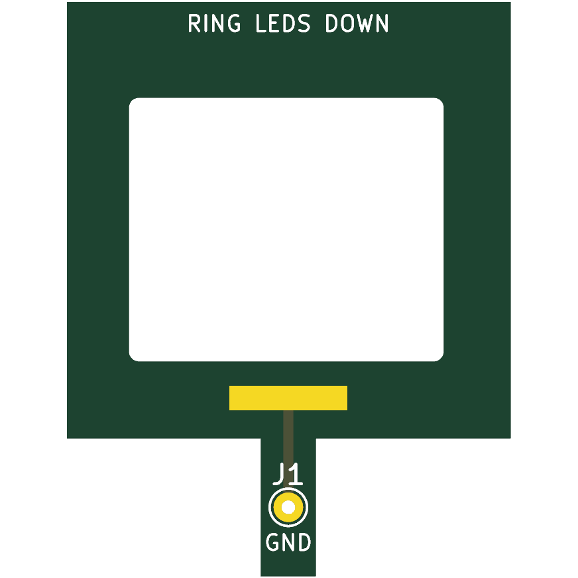
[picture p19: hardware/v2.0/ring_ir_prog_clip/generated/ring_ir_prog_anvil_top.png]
Anvil
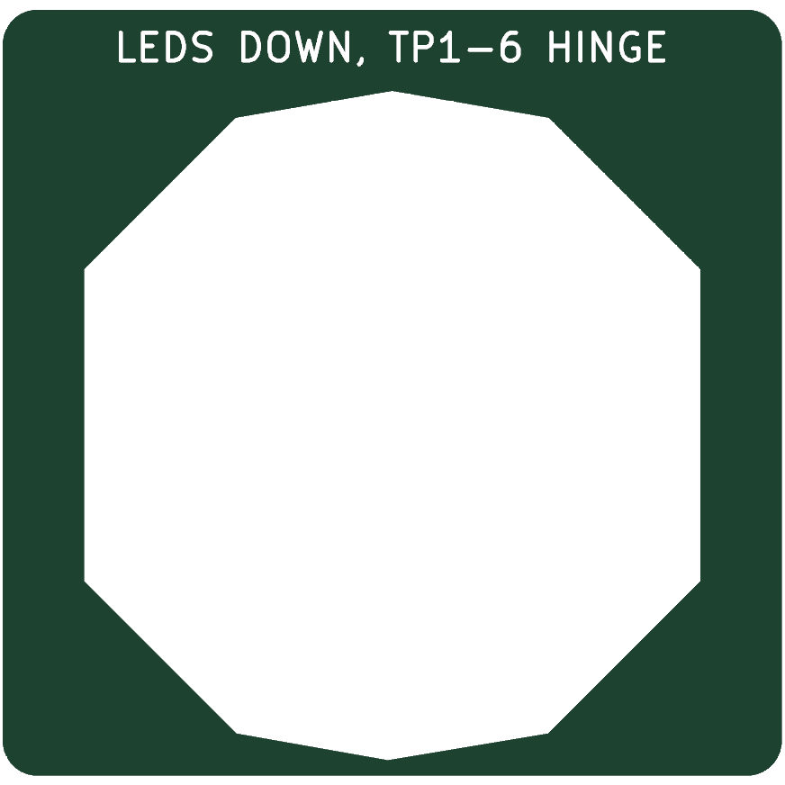
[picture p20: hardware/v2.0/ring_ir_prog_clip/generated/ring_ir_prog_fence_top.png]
Fence
|  |  |  |  |

## How it works

All components on the ring are on the front, so the rear is flat. The ring
goes into the clip **LEDs down**:

```
  header  pins           probe PCB (on top of the upper-jaw tip)
  ┌┴┐  ││ ││ ││ ┌───────┐ ← M2 screw through the jaw holes and both slots
 ═╧═╧══╪╪═╪╪═╪╪═│ upper │══  probe
       ││ ││ ││ │  jaw  │
 ══════╪╪═╪╪═╪╪═└───────┘══  guide (second probe board, unpopulated)
 ══════ ring_pcb_IR (rear up, LEDs down) ═══╗ ← pins land on TP1–TP6 + TP9
 ─fence─[ pocket locates the ring ]─fence─  ║ nut
 ─anvil─[ window clears parts ]▄ GND pad ─anvil──── tail (GND lead)
 ▓▓▓▓▓▓▓▓▓ printed riser (5 mm) ▓▓▓▓▓▓▓▓▓▓▓▓
         ▓ hook ┌──────── lower jaw ─────────
```

- **Probe board** (15.5 × 22.7 mm, the jaw width). Order two identical boards.
  They sandwich the upper-jaw tip, as on Adafruit 5434: the populated probe on
  top, the unpopulated copy underneath as a pin guide resting on the ring. Two
  M2 slots go through both boards and the jaw holes; the slots absorb the
  unmeasured hole spacing (7.8–10.2 mm). Seven P75-class pins are mirrored onto
  TP1–TP6 (3.05 mm grid) and TP9. TP9 is the VCC test point at the centre of
  the exposed battery pad. The pins are routed to a standard AVR ISP-6 header
  (J1) and a GND lead pad (J2). The header sits **in front of** the pin grid,
  so the jaw tip can sit just behind the pins and close over the ring.
- **Anvil board** (22.5 × 29.2 mm). Taped to the printed riser. A window
  clears every front courtyard. The ring rests on its side rails, the top band
  and a flat ENIG GND pad under the exposed front ground bar (TP8). A narrow
  tail pad (J1) takes the GND lead between the M2 nuts.
- **Fence board** (22.5 × 22.2 mm). Stacked on the anvil. Its pocket is the
  ring outline plus 0.15 mm, so the ring drops in at a fixed position. Its
  rear edge stops 0.6 mm past the ring so the M2 nuts clear it.
- **Riser** (printed). Lifts the anvil 5.0 mm, so
  the stack matches the 9.8 mm parallel jaw gap and the jaws close parallel.
  A hook drops in front of the lower-jaw tip to stop the stack sliding.
- **GND lead.** A short 30 AWG wire runs from probe J2 to anvil J1. GND is only
  on the ring's front, so it cannot be reached from the pogo side.

The probe layout matches the IR board's test-pad positions, electrical nets,
outline and component clearances. See [development.md](development.md) for
engineering source and regeneration details.

### Pin map

| Ring pad | Net | ATtiny85 function | ISP-6 pin |
| --- | --- | --- | --- |
| TP1 | PB0 | MOSI | 4 |
| TP2 | PB1 | MISO | 1 |
| TP3 | PB2 | SCK | 3 |
| TP6 | PB5 | RESET | 5 |
| TP9 | VCC | VCC | 2 |
| TP8 (front bar, via anvil) | GND | GND | 6 |
| TP4, TP5 | PB3, PB4 | spare GPIO (MCU and test pad only) | not routed; probe at the pin tops or omit the pins |

ISP-6 is the standard Atmel 2×3 2.54 mm layout (pin 1 MISO, 2 VCC, 3 SCK,
4 MOSI, 5 RESET, 6 GND), so USBasp, AVRISP mkII, Arduino-as-ISP and similar
programmers plug straight in. A ring inserted 180° the wrong way is harmless:
VCC still lands on the central pad, the signal pins land on solder mask, and
GND reaches the other bar.

## Clip dimensions (estimated)

The AliExpress listing has photos only. Dimensions come from the Adafruit 5434
datasheet (`C17220-001`, same clip family) and from its photos scaled by a US
quarter and the 2.54 mm header pitch. The two scales agree within about 3%.
The estimates carry ±1.0 mm uncertainty. Frame: x from the lower-jaw tip
toward the hinge; heights from the lower-jaw top.

| Dimension | Estimate | Source |
| --- | --- | --- |
| Overall length | 62.5 mm | Datasheet p8 drawing |
| Jaw width | 15.5 mm | Front photo, header-pitch scale |
| Lower jaw: tip thickness / tip length / throat thickness | 4.4 / 12.7 / 7.3 mm | Side photo |
| Upper-jaw tip setback from lower tip | 7.5 mm | Side photo |
| Upper jaw: tip thickness / tip section end / mid thickness | 4.4 / 12.7 / 7.0 mm | Side photo |
| Parallel jaw gap at the tip (clamped) | 9.8 mm | Side photo, Adafruit stack clamped |
| Gap at the throat | 5.6 mm | Side photo |
| Hinge pin | x ≈ 27.5 mm (about 47% of length) | Side photo, AliExpress image 6 |
| M2 holes in the upper-jaw tip | 2 across the width, ≈ 9 mm apart, ≈ 3.5 mm behind the tip | AliExpress image 6, Adafruit photos |
| Spring / U-block | x ≈ 56.5 / 41.5–62 mm | Side photo (visual only) |
| P75 pin | 16.5 mm long, 1.02 mm barrel, 2.5 mm travel | Datasheet p13–14 |

## FreeCAD fit check

The virtual fit check builds a parametric assembly of the following parts:

- the clip jaws, hinge, spring and U-block;
- the riser;
- the anvil and fence;
- the ring with component height boxes;
- the guide and probe boards;
- seven pins at working compression;
- the header;
- the M2 screws and nuts.

It runs boolean interference checks on each part pair (33 pairs touch) and
checks contacts and clearances, then sweeps each clip estimate by ±1 mm.
Detailed fit-check information is in [development.md](development.md).

| Clamped (section at u = 0) | Exploded stack |
| --- | --- |
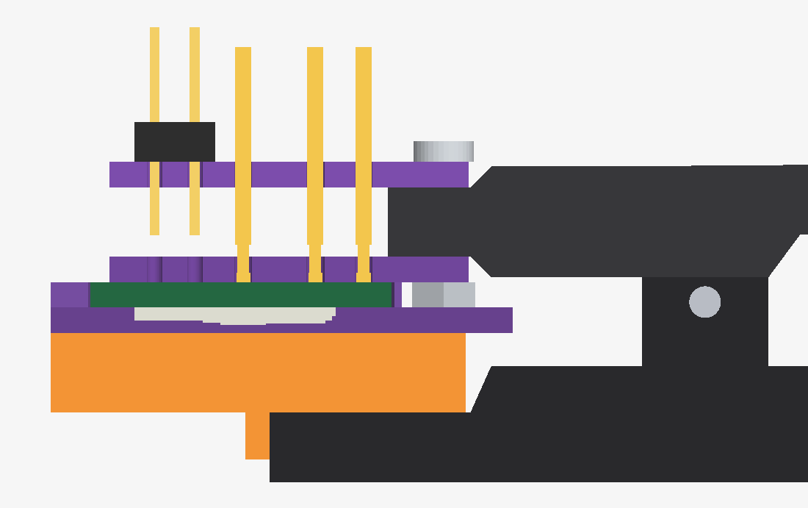
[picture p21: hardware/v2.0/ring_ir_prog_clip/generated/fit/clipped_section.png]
Section through the PB2/PB3/VCC pins
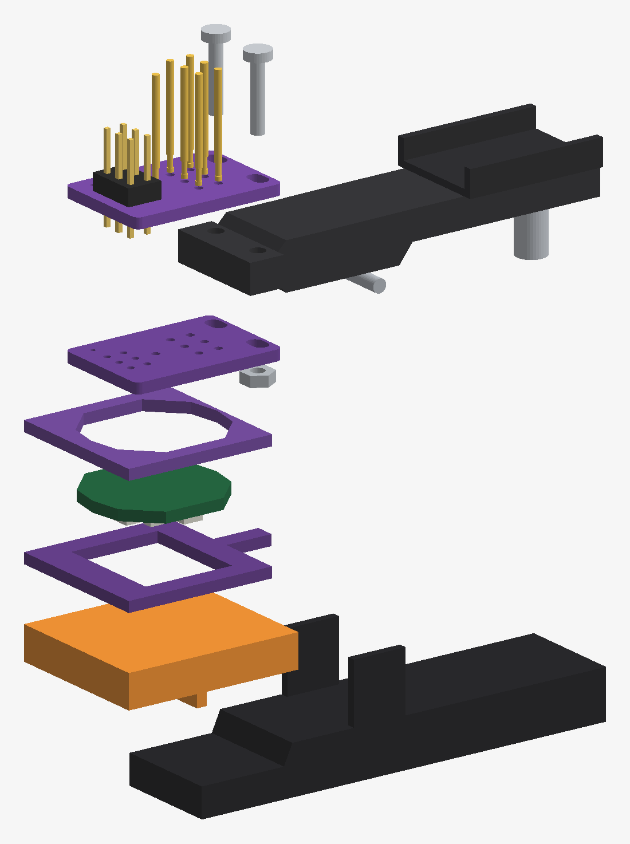
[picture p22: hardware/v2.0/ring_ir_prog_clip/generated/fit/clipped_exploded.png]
Exploded
|  |  |

Results at the nominal estimates:

| Check | Result |
| --- | --- |
| Interference between any two parts | none |
| Contacts (riser–jaw, guide–ring, jaw–guide, probe–jaw, pins–ring) | all touching, 0.000 mm |
| Stack (riser / anvil / ring / guide / jaw / probe top) | 5.0 / 6.6 / 8.2 / 9.8 / 14.2 / 15.8 mm |
| Jaw tilt at the clamped gap | 0.0° (riser sized to the parallel gap) |
| Pin compression | 1.65 mm, 66% of 2.5 mm travel |
| Pin position against the TP pad centres | 0.000 mm |
| Pin barrel to upper-jaw tip | 1.04 mm |
| Probe end to the upper-jaw step | 0.10 mm |
| M2 nut to fence/anvil; screw tip above riser | 0.65 mm; 0.80 mm |
| Ring parts to riser (inside the anvil window) | 0.35 mm |
| Header tails above the guide | 1.35 mm |
| Ring rear edge to the lower-jaw throat | 4.95 mm |

The ±1 mm sweep shows which dimensions to measure first:

- **Hole setback +1 mm or upper-tip setback +1 mm.** The probe end reaches the
  upper-jaw step. With the setback +1 mm the barrel also nears the jaw tip.
- **Upper tip section 1 mm shorter.** Same probe-end conflict.
- **Lower tip 1 mm shorter.** The riser end reaches the throat ramp.

All other ±1 mm cases still pass. The VCC pin sits 1.6 mm in front of the
lower-jaw tip; the riser carries that load.

## BOM

| Qty | Part | Notes |
| --- | --- | --- |
| 2 | Probe PCB, 1.6 mm | `fab/ring_ir_prog_probe.zip`; top is populated, the second is the pin guide |
| 1 | Anvil PCB, 1.6 mm, ENIG | `fab/ring_ir_prog_anvil.zip`; ENIG for the flat GND contact |
| 1 | Fence PCB, 1.6 mm | `fab/ring_ir_prog_fence.zip`; stack two for a deeper pocket if needed |
| 7 | P75-class pogo pin, 1.02 mm barrel | B1 spear or LM2 cone tip (head ≤ 1.05 mm, so it passes the 1.15 mm guide hole) |
| 1 | 2×3 2.54 mm pin header | Through-hole, on the top probe board |
| 1 | DIY pogo clip kit | Jaws, spring, M2 nuts |
| 2 | M2 × 10 pan-head screw | The kit's 12–16 mm screws are longer than the 9.2 mm grip and hit the riser |
| 1 | Printed riser | PLA or PETG, 100% infill |
| – | 30 AWG wire, VHB or double-sided tape | GND lead; holds the anvil/fence to the riser and the riser to the lower jaw |

## Before ordering: measure first

1. Measure the jaw with calipers and update the design settings. Start with the
   dimensions the sweep flags: the hole setback, the upper-tip setback and tip
   section length, the lower-tip length, the hole spacing, and the parallel
   gap with the clip closed on a 9.8 mm stack.
2. Measure the pogo pins: barrel diameter, length, travel and tip. Update the
   design settings, keeping the drill about 0.1–0.15 mm larger than the barrel.
3. Rebuild. The FreeCAD fit and the sweep must pass. The pins should reach
   the ring at about two-thirds of their travel when the clip is closed.

## Assembly

1. Solder J1 and the GND lead to J2 on the top probe board.
2. Screw the probe (top) and guide (underneath) to the upper-jaw tip with
   M2 × 10 screws through the slots. Put the nuts under the guide.
3. Insert the pins tip first from the top, through the probe and the guide.
   Set them so the tips stand 1.65 mm below the guide. In the clamped stack
   that is 66% of travel, and the barrel ends 0.75 mm above the guide. Solder
   them on the top board only.
4. Tape the riser onto the lower jaw, with its hook against the jaw tip. Tape
   the anvil to the riser and the fence onto the anvil. Solder the other end
   of the GND lead to anvil J1.
5. Insert a ring LEDs down into the fence and close the clip. The guide comes
   down flat onto the ring and fence. Nudge the anvil stack until the programmer
   reads the ATtiny85 signature consistently, then tape it down.

## Safety

- **Remove the CR2032 before programming.** The programmer's VCC drives the
  ring's VCC directly, and backfeeding a primary lithium cell is unsafe.
- Use a 3.3 V or 5 V programmer within the ATtiny85 and LED limits, and keep
  current limited.
- Always insert LEDs down. Face-up insertion lets pins hit components.

## Development

KiCad/FreeCAD regeneration, validation and source-file details are in
[development.md](development.md).

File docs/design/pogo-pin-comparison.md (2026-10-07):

# Pogo pin comparison for the v2 battery contacts

The v2 ring uses **two opposing SMT pogo pins** between the CR2032 and the
cassette. The negative pin sits in the Carrier and touches the inset bottom face
of the cell. The positive pin is soldered to the rear VCC pad of the PCB and
touches the top face of the cell. This document compares the current Mill-Max
part with low-cost AliExpress SMT pins and screens their fit in the current
tolerance stack. It is a **screening document, not a qualification**: no pin
listed here has been bought, measured, cycled or fitted.

## Sources

- **Mill-Max 0965-0-15-20-80-14-11-0**: official Mill-Max spring-loaded
  connector catalogue, page 24. The part numbers in
  `hardware/v2.0/ring_3d/parameters.json` match this catalogue.
- **AliExpress "100pcs SMT Pogo Pin Connector 1.8-22mm Test Probe"**:
  [listing 1005011917887337](https://www.aliexpress.com/item/1005011917887337.html).
  - The heights come from the seller's "POGO PIN SMT common sizes" table:
    total length A, plunger B, barrel C, compressed height.
  - The flange and tip diameters come from the seller's drawing of the 2.0 mm pin:
    [image](https://ae-pic-a1.aliexpress-media.com/kf/S9ab0259f409f43fd8efaef80ae22f9f5P.jpg).
  - The seller gives no tolerances, spring force, plating thickness, cycle
    life or current rating. The other sizes in the listing may not share the
    2.0 mm drawing's flange or tip dimensions.

## Dimensions

| Part | Free height | Compressed | Stroke | Barrel Ø | Flange Ø x thickness | Tip Ø | Height tolerance |
| --- | ---: | ---: | ---: | ---: | --- | ---: | ---: |
| Mill-Max 0965 (current) | 2.54 | 1.93 | 0.61 | 1.626 | 1.829 x 0.711 | 1.067 | ±0.1524 (published) |
| AliExpress 1.6 mm | 1.60 | 1.34 | 0.26 | ? | ? | ? | not stated |
| AliExpress 1.8 mm | 1.80 | 1.48 | 0.32 | ? | ? | ? | not stated |
| AliExpress 2.0 mm | 2.00 | 1.60 | 0.40 | 1.5 | 2.0 x 0.3 | 0.9 | not stated |
| AliExpress 2.5 mm | 2.50 | 2.0 or 1.75 | 0.50 or 0.75 | ? | ? | ? | not stated |
| AliExpress 3.0 mm | 3.00 | 2.30 | 0.70 | ? | ? | ? | not stated |

All dimensions are in mm. "?" means the listing does not give the value. The
seller's table shows two compressed heights for the 2.5 mm pin; check which
version you receive.

## Tolerance-stack screen

The current design reserves **±0.05 mm** for the printed stack and **±0.05 mm**
for cell thickness. The working compression must stay inside the stroke after
adding those to the pin's own height tolerance:

`worst = 0.05 + 0.05 + pin tolerance`

The working range is `worst ≤ compression ≤ stroke − worst`. If that range is
empty, a worst-case pin either loses contact or bottoms out on the cell.

| Part | Pin tolerance | Usable compression | Margin | Two-pin height saving vs Mill-Max |
| --- | ---: | --- | ---: | ---: |
| Mill-Max 0965 | ±0.1524 | 0.252–0.357 | 0.105 | baseline |
| AliExpress 1.6 mm | ±0.05 | **none** | — | — |
| AliExpress 1.8 mm | ±0.05 | 0.150–0.170 | 0.020 | +1.19 |
| AliExpress 1.8 mm | ±0.10 | **none** | — | — |
| AliExpress 2.0 mm | ±0.05 | 0.150–0.250 | 0.100 | +0.87 |
| AliExpress 2.0 mm | ±0.10 | **none** | — | — |
| AliExpress 2.5 mm (2.0 compressed) | ±0.10 | 0.200–0.300 | 0.100 | −0.03 |
| AliExpress 2.5 mm (2.0 compressed) | ±0.15 | **none** | — | — |
| **AliExpress 2.5 mm (1.75 compressed)** | ±0.10 | 0.200–0.550 | 0.350 | +0.22 |
| **AliExpress 2.5 mm (1.75 compressed)** | ±0.15 | 0.250–0.500 | 0.250 | +0.22 |
| AliExpress 3.0 mm | ±0.15 | 0.250–0.450 | 0.200 | −0.83 (taller) |

Height saving compares two pins at mid-window compression against the
Mill-Max working height of 2.2352 mm. A positive value lowers the crown.

## Assessment

| Option | Verdict | Reason |
| --- | --- | --- |
| Mill-Max 0965 | **Keep as the reference design** | Published tolerance, force and plating. The current CAD and validator are built around it. |
| AliExpress 2.5 mm, 1.75 mm compressed | **Best low-cost candidate** | Has the most margin: it still has a 0.25 mm working range at ±0.15 mm pin tolerance. Saves about 0.2 mm of height. |
| AliExpress 2.5 mm, 2.0 mm compressed | Marginal | Fails if the pin tolerance is worse than about ±0.10 mm. |
| AliExpress 2.0 mm | Not recommended | Only 0.4 mm of stroke. It works only if the pins are held to ±0.05 mm, which is unlikely for unspecified parts. |
| AliExpress 1.6 / 1.8 mm | Reject | Too little stroke to cover the printed-part and cell tolerances. |
| AliExpress 3.0 mm | Works, but taller | Plenty of margin, but it raises the crown by about 0.8 mm. |

A thinner PCB is the more reliable way to lower the crown.
[OSH Park's 2oz-0.8mm service](https://docs.oshpark.com/services/two-layer-hhdc/)
(0.8 mm ±0.07 mm) would lower it by 0.8 mm without reducing the pin travel. The
generator reads the thickness from `ring_mono.kicad_pcb`.

## CAD changes needed for an AliExpress pin

With the current pocket geometry, `validate_parameters()` rejected every 2.5 mm
variant screened, using 0.3 or 0.5 mm flanges at ±0.10 or ±0.15 mm tolerance.
Adopting one requires:

1. **Measured pin parameters.** Set `pin_initial_height`, `pin_max_stroke`,
   `pin_body_diameter`, `pin_body_length`, `pin_flange_diameter`,
   `pin_flange_thickness`, `pin_tip_diameter` and `pin_height_tolerance` from
   measured samples, not from the listing.
2. **Bores.** Reduce `pin_bore_diameter` from 1.75 mm to about 1.6 mm so a
   1.5 mm barrel does not tilt. Keep `pin_flange_bore_diameter` larger than the
   measured flange, and keep the barrel bore smaller than the flange.
3. **Flange capture.** A 0.3 mm flange is too thin for the current positive pin
   shoulder in the ContactDeck. Raise `deck_floor_top` or redesign the shoulder,
   and keep the 0.6 mm wiring clearance under the PCB support lip.
4. **Compression.** Set `pin_compression` to the middle of the working range,
   about 0.375 mm for the 2.5/1.75 pin. The stack then moves `battery_bottom`
   and `pcb_bottom`. The validator requires the positive flange to sit 0.05 mm
   below the PCB.
5. **Rebuild.** Regenerate the CAD and roadmap renders, update the
   height-dependent tests and checks, and review the same-scale comparison.

## Sample measurement plan

Buy the 2.5 mm size, plus the 2.0 mm size if you are curious. Measure at least
10 pins of each with a micrometer or calibrated height gauge:

- Free height A, compressed (bottomed) height and barrel length C.
- Flange diameter and thickness; barrel and tip diameters.
- Force at the planned working compression and at full stroke, measured with a
  gram gauge or scale on a fixture.
- Contact resistance against a CR2032 face before and after 500 compression
  cycles and a short sweat/humidity exposure.
- Plating: check for exposed base metal after cycling. Avoid pins where the tip
  plating wears through.
- Solder: reflow or hand-solder a sample to a rear VCC pad and confirm that the
  plunger still moves freely without wicked solder.

Use the measured maximum deviation as `pin_height_tolerance`. Reject the batch
if the free height or the stroke differs from the seller's table by more than
the assumed tolerance.

## Safety and electrical notes

- The CR2032 rim and top are positive. The negative tip must stay on the inset
  bottom face. The validator checks the tip radius plus the 0.1 mm cell
  tolerance against a 6 mm minimum negative-face radius. Narrow tips are fine.
- Do not compensate for a short pin with shims, solder blobs or conductive
  adhesive under the plunger.
- None of these options is qualified for wear, sweat exposure, drop or battery
  safety. Bench and wear testing are still required before giving rings to
  users.

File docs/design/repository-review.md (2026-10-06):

# Repository baseline review

Reviewed 2026-10-06 for the FreeCAD v2 physical-hardware revision.

## Consolidation

The remote default is `main`. There were **no open PRs** when work began.
Previous mono-colour, Qi, TV-B-Gone routing and decorative-model feature PRs
were already merged, including #17 at baseline `dc84f6d`. Local `main` was
behind that baseline and was fast-forwarded without dropping any work.

The sole remaining unmerged remote branch, `feat/dotstar-colour` at `b5a6b6a`,
added an independent APA102/ATtiny85 board experiment in its own directory.
It was merged with history preserved, not squashed over another variant.
It remains explicitly **experimental**, not a routed or fabrication-ready board.
All existing feature tips are included in consolidated `main`.

## Design inventory and findings

| Area | Evidence and consequence |
| --- | --- |
| v1 FreeCAD | Large historical document containing the multi-colour PCB, CR2032 and many cosmetic variants. Preserve it; do not assume its 17.78 mm octagon is the v2 PCB profile. |
| v2 mono | Six LED footprints, front `/GND` test pads and a rear VCC plane with exposed central contact. Actual outline is 17.78 x 19.05 mm. The new contact deck derives its outline and net assignments from this board. |
| v2 IR | ATtiny85/IR design with a separate ground/power/programming pad map. Its existing routed PCB and Gerbers were retained unchanged; v2 mono contact compatibility does not imply IR compatibility. |
| DotStar | APA102/ATtiny85 schematic and initial board placement, with **five unconnected items**. Do not fabricate until power, routing, ERC/DRC and battery suitability are completed. |
| Battery interface | Existing mono ground is on the front, while VCC is exposed on the rear. Two arbitrary rear-facing pogo pins would not make a functional contact interface. New hardware uses a permanent insulated loom and pogo tips on opposite cell faces. |
| LED power | The mono board has no explicit series-current limiter. Geometry does not establish safe LED/cell current or temperature; these remain release blockers for a wearable assembly. |
| Qi proposal | Documentation only, not a CR2032 charging design. A primary CR2032 must never be charged. |
| Firmware | Separate legacy Arduino/ATtiny85 TV-B-Gone port with upstream attribution/license. The mono ring needs no firmware; no firmware changes were made. |
| Materialator | Separate numpy-stl experiment. Its existing test calls missing `somefile.stl`; it is not a CAD-generation or hardware acceptance test. Metal-density/mesh-unit handling is outside this enclosure change. |

KiCad 10 read-only DRC of the mono baseline reported **zero unconnected items,
zero errors and 12 warnings**: six library-footprint mismatches and six
silkscreen/mask clipping warnings. The DotStar baseline reported two
library-footprint warnings and five unconnected items. These pre-existing
issues were not hidden or represented as newly repaired. No PCB source or
fabrication data was changed by the physical-hardware revision.

## v2 physical implementation

See [assembly, contact BOM, regeneration and release gates](../../hardware/v2.0/ring_3d/README.md).
The new design contains a keyed 30-degree three-lug bayonet carrier, removable
PCB/contact deck, screw-retained bezel, insulated CR2032 well, two specified
spring contacts and a mandatory anti-unlock screw. Both battery contacts are
serviceable without soldering to the cell.

The repository now includes Copilot instructions, a tool-neutral reconstruction
skill, portable interface/invariant regression tests and provenance checks.
Native FreeCAD and manufacturing exports are committed with their validation
report. Virtual checks are **not** a claim of printing, electrical testing,
drop/wear qualification, waterproofing or battery-compartment certification.

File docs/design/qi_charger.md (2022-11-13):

# QI Charger in ring design

Reference [prior art](https://github.com/olliiiver/kicad_qi)

## Main Components
The following main components are proposed
- Texas Instruments [BQ51003](https://www.ti.com/lit/ds/symlink/bq51003.pdf?ts=1667101441728)
- Texas Instruments [BQ51013B](https://www.ti.com/product/BQ51013B)
- Air core transformer [secondary coil](https://www.aliexpress.com/item/1005004150745110.html)
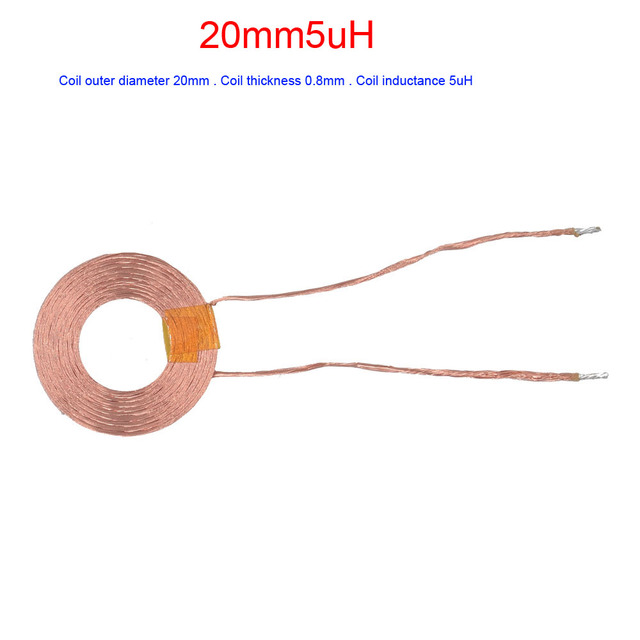
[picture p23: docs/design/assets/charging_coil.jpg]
Charging Coil

- Off the shelf [receiver](https://www.aliexpress.com/item/1005002341447996.html)

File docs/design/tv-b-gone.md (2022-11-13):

# IR TV Turn-off mode
The Infrared LED's in the ring can be used in TV-B-Gone mode to broadcast shutdown signals to devices in range. From TV's to Airconditioning units. Perhaps appropriate for a spooky Halloween effect where someone in a costume can turn devices off by proximity.

Inspired by [Adafruit Kit](https://github.com/adafruit/TV-B-Gone-Kit).
Modernized take [SMD Version](https://github.com/zookzook/tv-b-gone-smd).

## Main Components
- [InfraRed LED Transmitters]()
- Minimal MCU to broadcast codes

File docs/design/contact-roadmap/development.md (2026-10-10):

# Contact roadmap development

Source and development notes for local FreeCAD concept illustrations and
optional Nano Banana image generation. The concepts do not replace the v2
manufacturing CAD.

## Local FreeCAD concepts

- `render_concepts.py` renders the four local concept images.
- `test_roadmap.py` checks the local illustration outputs.
- `images/local-freecad/manifest.json` records local render provenance.
- `contact-paths.svg` is the authored contact/isolation topology diagram.

Rebuild and test with FreeCAD's bundled Python:

```powershell
& 'C:\Program Files\FreeCAD 0.19\bin\python.exe' docs\design\contact-roadmap\render_concepts.py
python -m unittest discover -s docs\design\contact-roadmap -p "test_roadmap.py"
```

## Optional Nano Banana generation

Generation is not currently verified: no authenticated image API access is
available. The five prompts are in `prompts.json`; `generate_nano_banana.py`
has offline request/response tests and calls the
[Gemini image API](https://ai.google.dev/gemini-api/docs/image-generation).
The default model is Nano Banana 2, `gemini-3.1-flash-image-preview`, as listed
by the [official Gemini CLI extension](https://github.com/gemini-cli-extensions/nanobanana).

From the repository root:

```powershell
python docs\design\contact-roadmap\generate_nano_banana.py --dry-run
# Set an API key securely in the environment; never add it to a tracked file.
python docs\design\contact-roadmap\generate_nano_banana.py
# Use a fresh output directory for reviewed iterations.
python docs\design\contact-roadmap\generate_nano_banana.py --stage 04-floating-metal --output docs\design\contact-roadmap\images\nano-banana-metal-iteration-2
```

Only authored text prompts are sent. Calls may incur provider charges. The
client accepts `NANOBANANA_API_KEY` and documented Gemini/Google fallback key
variables; it does not print or commit keys. Authentication, model availability
and quota are required. Errors are explicit. Successful runs write images and
a provenance manifest; review all output before embedding it because generated
imagery can depict unsafe or impossible electrical/mechanical relationships.
Do not use it to select dimensions or prove compliance.

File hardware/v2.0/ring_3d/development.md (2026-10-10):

# Lantern Ring v2 development

This document contains source-file references and regeneration commands for
the FreeCAD model, Lantern Corps crowns, and Blender renders. Run commands from
the repository root on Windows.

## Source and generated files

- `parameters.json` contains the mechanical stack and fit values.
- `design.py` reads the KiCad interface and validates design parameters.
- `lantern_ring.py` builds the FreeCAD assembly and checks geometry.
- `build.FCMacro` opens the model in the FreeCAD GUI.
- `crowns.py` builds the eight low-profile crowns from `logos/logos.json`;
  `--extract` traces the source emblems from the v1 FreeCAD document.
- `animation/export_parts.py` exports assembled parts and crown meshes for
  Blender.
- `animation/animate.py` produces the assembly animation and crown lineup.
- `animation/corps_swap.py` produces the crown-swap animation and hero still.
- `animation/render.ps1` and `animation/render_corps.ps1` run the render
  pipelines.

FreeCAD's bundled Python must run the CAD generators. The portable design and
crown tests use ordinary Python 3.8+. The checked-in CAD was generated with
FreeCAD 0.19 / OCC 7.5; rerun validation when changing FreeCAD versions.

## Rebuild and validate

```powershell
python -m unittest discover -s hardware\v2.0\ring_3d -p "test_design.py"
& hardware\v2.0\ring_3d\build.ps1
& 'C:\Program Files\FreeCAD 0.19\bin\python.exe' hardware\v2.0\ring_3d\test_freecad.py
& 'C:\Program Files\FreeCAD 0.19\bin\python.exe' hardware\v2.0\ring_3d\crowns.py
python -m unittest discover -s hardware\v2.0\ring_3d -p "test_crowns.py"
```

To re-trace the v1 logos before rebuilding the crowns, run:

```powershell
& 'C:\Program Files\FreeCAD 0.19\bin\python.exe' hardware\v2.0\ring_3d\crowns.py --extract
```

If FreeCAD auto-discovery chooses a different installation, pass the bundled
interpreter explicitly:

```powershell
& hardware\v2.0\ring_3d\build.ps1 -FreeCADPython 'C:\Program Files\FreeCAD 0.19\bin\python.exe'
```

For parametric GUI edits, run `build.FCMacro` in a new FreeCAD session before
opening an existing FCStd. Change the linked `Parameters` object and recompute.
Copy intended changes into `parameters.json` and rebuild; GUI edits do not
update exported manufacturing files. The PCB interface embedded in FCStd is a
snapshot, so regenerate after PCB changes. Do not hand-edit generated geometry.

## Render animations and images

Build the v2 parts and crowns before running either render script. The crown
swap pipeline consumes the crown meshes produced by the assembly export.

```powershell
& hardware\v2.0\ring_3d\animation\render.ps1
& hardware\v2.0\ring_3d\animation\render_corps.ps1
```

Use `-Preview` on either script for a draft. The assembly render produces
`generated/lantern_ring_v2_assembly.mp4`, `.gif`, and
`generated/crowns/lineup.png`. The Corps render produces
`generated/lantern_corps_swap.mp4`, `.gif`, and `generated/crowns/hero.png`.
Intermediate meshes, scenes and frames are written under `animation/build/`.

The assembly pipeline exports parts with `export_parts.py`, renders through
Blender 5 EEVEE, then encodes MP4/GIF with ffmpeg. If rebuilding the crowns,
run `crowns.py` before the assembly render so both animation pipelines use
current crown geometry.

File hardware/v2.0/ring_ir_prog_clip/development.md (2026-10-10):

# IR programming clip development

This document contains source references and regeneration steps for the KiCad
probe/anvil/fence boards and their FreeCAD fit check. Run commands from the
repository root.

## Source files

- `parameters.json` contains PCB layout, clip-kit estimate and pogo dimensions.
- `generate.py` reads the target IR PCB and creates the probe, anvil and fence
  boards and their electrical schematics.
- `check_reports.py` validates ERC/DRC reports and records source provenance.
- `fit_check.py` builds and checks the clip stack in FreeCAD.
- `test_prog_clip.py` checks the PCB interfaces and generated fit report.
- `build.ps1` runs the complete KiCad and FreeCAD pipeline.

The board geometry is derived from the v2 IR PCB's pads, nets, outline, front
mask opening and component courtyards. Estimated clip-kit geometry is based on
photos and the Adafruit 5434 family datasheet; it is not a measured fit.
Pin dimensions are likewise unmeasured. Update the configuration only after
measuring the physical clip and pogo pins, and mark the estimates as measured
in the configuration.

## Rebuild and validation

Requires KiCad 10 and FreeCAD 0.19 or newer:

```powershell
& hardware\v2.0\ring_ir_prog_clip\build.ps1 -Fab
python -m unittest discover -s hardware\v2.0\ring_ir_prog_clip -p "test_prog_clip.py"
```

The build runs the PCB generator, schematic/ERC/DRC checks, exports PDFs,
renders and STEP, and optionally exports Gerbers and Excellon drill files.
It then checks the reports and runs the FreeCAD fit verification. Use
`-SkipFit` only when intentionally bypassing the fit step.

The portable test does not require `pcbnew`; it verifies pogo positions and
nets, ISP-6 pinout, anvil ground contact, courtyard/window clearance, board
spacing, assembly fit and input provenance. Do not hand-edit generated KiCad
boards or fabrication files. Update the source parameters and rebuild.

After assembly, check that `avrdude -c usbasp -p t85` consistently reads the
ATtiny85 signature `0x1e930b` before securing the anvil stack in place.

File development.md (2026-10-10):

# Development

Project-specific source references and regeneration workflows:

- [Lantern Ring v2 FreeCAD and Blender](hardware/v2.0/ring_3d/development.md)
- [IR programming clip KiCad and FreeCAD](hardware/v2.0/ring_ir_prog_clip/development.md)
- [Contact roadmap illustrations and prompts](docs/design/contact-roadmap/development.md)
- [Arduino TV-B-Gone firmware](firmware/Arduino-TV-B-Gone/development.md)

These documents are intended for contributors. Product overviews, assembly
guidance, visuals and purchasing information remain in the corresponding
READMEs.

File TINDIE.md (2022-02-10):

#### What is it?

Custom made prop/jewellery/cosplay accessory modelled after lantern corp rings from the DC Universe.

#### Why did you make it?

I have always been fascinated by the green lantern ring from reading DC comics of the Green Lanterns and Justice League. When I watched the movie and collected the darkest night brightest day series, this interest solidified. I started making these rings derived from the idea of LED throwies with cut cans providing the body and LED's spanning a coin cell providing the light. As I have gained skills in mechanical and electronics design over the last 10 years, this has morphed into a product I am proud to sell to other fans rather than a novelty I give out in pubs and clubs to make friends.

#### What makes it special?

This lantern rings are 3D printed to the measurements of the wearer on demand and use brightest LED's available within the coin cell voltage limits. They are also fully open-source and follow the logos of all the 10 different lantern variants. Colour variants are available:
- White (Life)
- Black Light/UV (Death)
- Red (Rage)
- Orange (Avarice)
- Yellow (Fear)
- Green (Will)
- Blue (Hope)
- Indigo (Compassion)
- Violet/Pink (Love)
- Invisible/IR

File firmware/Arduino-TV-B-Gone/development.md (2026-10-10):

# Arduino TV-B-Gone development

Source-file references and build notes for the legacy ATtiny85 Arduino port.
The firmware was last documented in 2016; verify toolchain compatibility
before changing or distributing a build.

## Source files

- `Arduino-TV-B-Gone.ino` contains the Arduino sketch and its version history.
- `main.h` configures the pin assignments, debug output and timing.
- `WORLD_IR_CODES.h` contains the regional IR power-code database.

Use the Arduino IDE to build for the intended ATtiny85 hardware. The sketch
expects the external IR LED, trigger button and optional region switch wiring
described in the user README. Confirm the MCU clock before changing
`DELAY_CNT`; timing must be tested on the target hardware.

The code lineage, original licensing and external background links are
documented in the user README. Preserve upstream attribution and license terms
when modifying or redistributing this code.

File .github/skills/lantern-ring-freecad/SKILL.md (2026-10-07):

---
name: lantern-ring-freecad
description: Rebuild and modify Lantern Ring v2 FreeCAD hardware, including the keyed bayonet PCB cassette, CR2032 pogo contacts, insulation, print exports, and mechanical validation.
---

# Lantern Ring FreeCAD reconstruction

The contact/material ideation roadmap is `docs/design/contact-roadmap/README.md`.
Its copper-foil, plated-leaf and metal-shell illustrations are not validated
replacement geometry. Keep the metal shell floating and retain a continuous
insulating contact/battery insert unless a separately reviewed design changes it.

The ATtiny85 IR board's programming fixture is a KiCad generator, not FreeCAD:
see `hardware/v2.0/ring_ir_prog_clip/README.md`. Do not reuse the mono-board
contact map for it.

Use this skill for Lantern Ring enclosure, PCB fit, battery contacts, FreeCAD
regeneration, printing or mechanical review. Work from
`hardware/v2.0/ring_3d/README.md`, `parameters.json`, `design.py` and
`lantern_ring.py`; the values below are reconstruction invariants, not permission
to replace measured geometry with a generic circle.

## Tool-neutral design invariants

- The supported mono PCB has a **17.78 x 19.05 x 1.6 mm** ten-vertex profile.
  Derive vertices from its real Edge.Cuts. KiCad (136.906, 83.185) is CAD XY zero;
  convert `(x, y)` to `(x - 136.906, 83.185 - y)`. Do not mirror the board.
- Front TP1 `/GND` is CAD (-0.0254, +7.493). Rear exposed VCC is
  CAD (0, +0.381), radius 2.962124. Preserve net/filled-copper/mask verification.
  Other board variants have different contact assignments.
- Four prints: band/socket RingBase, bayonet Carrier, removable ContactDeck
  and screw-retained Bezel. The **entire cassette rotates**, not bare PCB edges.
- Three lugs at 0/120/240 degrees have widths 24/14/14 degrees. Slots add
  2 degrees per flank; 30-degree counterclockwise twist seats them under shelves.
  The wide lug cannot enter either narrow slot. A radial M1 x 2 screw at the
  locked wide lug prevents accidental counterrotation; it is mandatory.
- The PCB pocket is profiled, not a positive 180-degree orientation key at
  printing clearance. Align front TP1 to the bezel's ground-wire relief.
- Measure legacy `Tube001` setting (22 mm diameter / 5 mm above PCB) and
  `Tube019` band (18.5 mm bore / 11 mm width) from the v1 native assembly.
  Use README photos for proportions, not calibrated dimensions. Keep the
  generated same-scale mesh/solid comparison and reference hashes current.
- Compact outer socket radius 12.45; socket 10.85; carrier 10.65; lug reach 11.45;
  groove reach 11.65 mm. Preserve at least 0.8 mm remaining outer track wall,
  radial running clearance and positive axial retention.
  Upper bezel diameter is 23.4 mm; band width remains 11 mm and wall 1 mm. This is still
  larger/taller than the original direct-contact body: do not claim exact fit
  or scale the cell/PCB to hide the difference.
- The band is OPEN at the bottom: two 1 mm PA12 arms, 60-degree missing sector,
  0.5 mm-radius caps and unloaded tip gap 8.75 mm. Build from continuous arcs
  and end-cap arcs, not tangent unions that leave nonwatertight mesh seams.
  Raise the bore apex to Z=0.3 and cut it from the crown underside: the band
  centre is `0.3 - bore/2`. Preserve the continuous 0.5 mm insulating floor.
  Opening is in the finger band only, never through the battery compartment.
  `BandGapAngle` is an editable native property.
- Hollow 1 mm conical shoulder walls (`shoulder_angle` 30-45 deg from the crown
  axis, default 40) run from the 12.45 mm crown rim to the band, like the legacy
  slanted side plates; keep the front-to-back pockets open (material, powder
  removal). `design.shoulder()` gives the meet point (61.7 deg from crest).
- Lower shank tapers on one plane per side from 11 mm at the crest to
  `band_tip_width` 6 mm, then `makeFillet(band_edge_radius=0.35)` on all band
  edges for a comfort-fit profile. A kinked taper makes the fillet invalid. OCC
  fillets here are C0 BSplines: use `bop_check()` (tolerates only C0 flags) and
  `exact_bounds()` (BoundBox is loose on BSplines) rather than relaxing checks.
- Material elasticity supplies fit spring-back, not an extra mechanical spring.
  `fit_expansion=1` is an unqualified screen. Preserve neutral-axis arc length
  for the illustration; `wall/2 * (1/R - 1/(R + expansion/2))` gives 0.250%
  nominal strain, not root strain or allowable fatigue. Shoulders stiffen the
  root: `free_arm_strain` scales it by arm/free-arm angle (0.425%), with a 0.5%
  ceiling; 15.5/16.5 mm bores need `fit_expansion` 0.7. No qualified size range,
  spring force or wearable safety claim without PA12 coupon/force/creep tests.
- Cell is CR2032, **+ up**, nominal radius 10 and thickness 3.2 mm.
  Its positive top and case/rim must remain isolated from the inset negative
  bottom face. Negative tip is centred; upper positive tip is at the VCC XY.
- Use two Mill-Max 0965-0-15-20-80-14-11-0 SMT pins, opposite-facing, or rederive
  **every** bore/shoulder/mount/stack dimension for a replacement. Free height
  2.54, working compression 0.3048, full stroke 0.6096, barrel diameter 1.626,
  base 1.829 x 0.7112, no projecting tail, tip diameter 1.067 mm.
- Battery bottom/top Z = 3.5352/6.7352. Negative flange datum Z = 1.3;
  positive flange datum Z = 8.9704. PCB bottom/top = 9.0204/10.6204;
  bezel top = 11.2204 mm. Include the LEDs at Z=11.7204: true above-finger
  profile is 11.4204 mm, not just bezel height. Pin length tolerance +/-0.1524 plus **measured**
  +/-0.05 each cell/finished stack permits 0.0524..0.5572 mm compression.
  Do not assume ordinary prints or unsorted cells meet those budgets.
- Insulated ground lead fits below the PCB, outside the battery pocket.
  Nonconductive epoxy secures the pins without entering plungers. Black wire
  (jacket <=0.4 mm) passes through the side duct to front ground.
  Upper SMT base solders directly to rear VCC through a 0.05 mm solder land:
  three permanent joints, no red wire, no battery soldering. Do not claim a
  solderless PCB interface. Store black service slack in the underside groove.
  Two M1 x 4 bezel screws sit outside the battery extraction cylinder.
  Qualify the 0.5 mm well wall, 0.8 mm track wall, M1 threads and 1 mm lugs with
  a controlled PA12 process; these are not qualified coarse-FDM dimensions.
- The 20 mm cell cannot pass through the smaller PCB pocket. Remove the bezel
  and lift PCB/deck together using wire slack before extracting the battery.

## FreeCAD execution

Run the root-relative PowerShell commands:

```powershell
& hardware\v2.0\ring_3d\build.ps1
python -m unittest discover -s hardware\v2.0\ring_3d -p "test_design.py"
& 'C:\Program Files\FreeCAD 0.19\bin\python.exe' hardware\v2.0\ring_3d\test_freecad.py
```

For GUI regeneration run `build.FCMacro`. Import the local `lantern_ring`
module before restoring the FeaturePython document for editing. The four
exposed dimension overrides on `Parameters` recompute all affected shapes;
the full configuration is JSON. Transfer final GUI settings back to
`parameters.json` and regenerate **all** exports. Saved PCB geometry is a
snapshot: PCB changes require regeneration, not just FCStd recompute.

STLs are print-oriented and bed-aligned; STEP is in assembly coordinates.
Keep solid BOP checks, pairwise unintended-interference checks, insertion/twist
pose sweeps, incorrect-key rejection, locked pullout rejection, cell extraction,
tip/face contact tests and native/export roundtrips. Pogo/lead termination
overlap is intentional; no other collision is acceptable.
Check the open bottom across the entire band width, the retained finger-side
floor and highest-LED profile. Regenerate `flex-fit.png` with its unqualified
curvature-screen labels, never present it as deformation FEA.

FreeCAD 0.19 / OCC 7.5 pitfalls: importing `FreeCAD` must precede `Part`;
refining the complex socket/carrier with `removeSplitter()` can damage curve-on-surface
geometry. Preserve its valid unrefined solid. STEP reader numerical checks use
an explicit 1e-5 mm tolerance, with unchanged volume and pre-normalization
topological validity. Weld duplicate mesh vertices, then require watertightness;
do not fill holes or discard faces to make a failed mesh appear printable.

## Completion criteria

Commit parameter/source changes alongside FCStd, assembly/per-part STEP,
per-part watertight STL, preview PNGs and the validation report. Ordinary Python
tests must pass and the report must match PCB/source hashes. Maintain assembly,
contact BOM, sourcing link and prototype limitations in the hardware README.

Virtual validation is not bench qualification. Require split-arm force/recovery,
root strain, sustained-deflection creep and fatigue tests as well as first-print fit,
adhesive/screw retention, wear/drop tests, wire-slack battery replacement,
loaded continuity/contact resistance, current/temperature and reverse/short
checks before wearing or release. No charging of a primary CR2032; adult
prototype only, with no battery-compartment certification claim.

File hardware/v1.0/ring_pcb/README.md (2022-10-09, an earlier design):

# Single LED choices

White - IN-S126ASUW
InfraRed - 
Red - APHCM2012QBC/D-F01
Orange - APTL3216SECK-01
Yellow - APTL3216SYCK
Green - APTD3216MGC
Blue - SM1206UV-400-IL
Indigo - 
Violet - APTR3216-VFX
UV -

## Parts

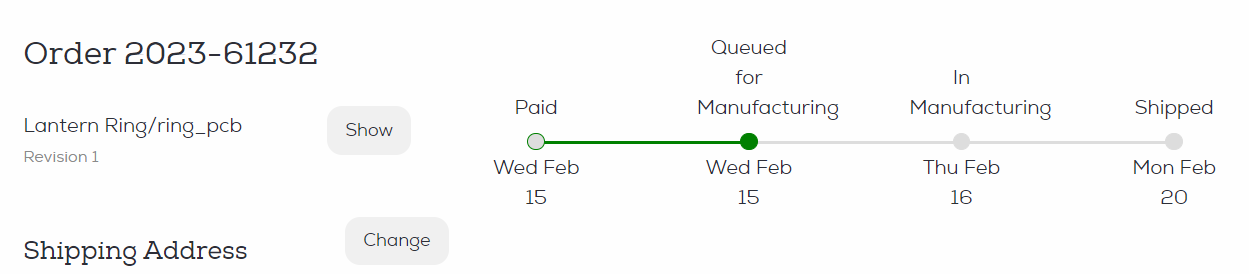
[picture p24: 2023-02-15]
docs/aisler_order.PNG

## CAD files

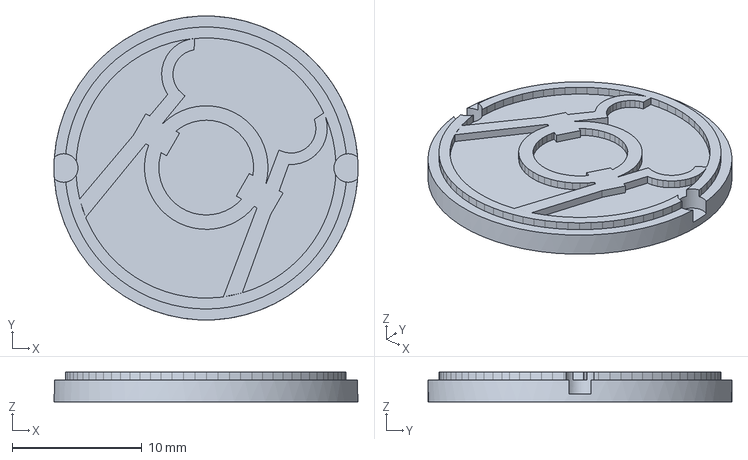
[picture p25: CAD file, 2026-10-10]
hardware/v2.0/ring_3d/generated/crowns/Crown_rage.step
23.4 x 23.4 x 2.30 mm

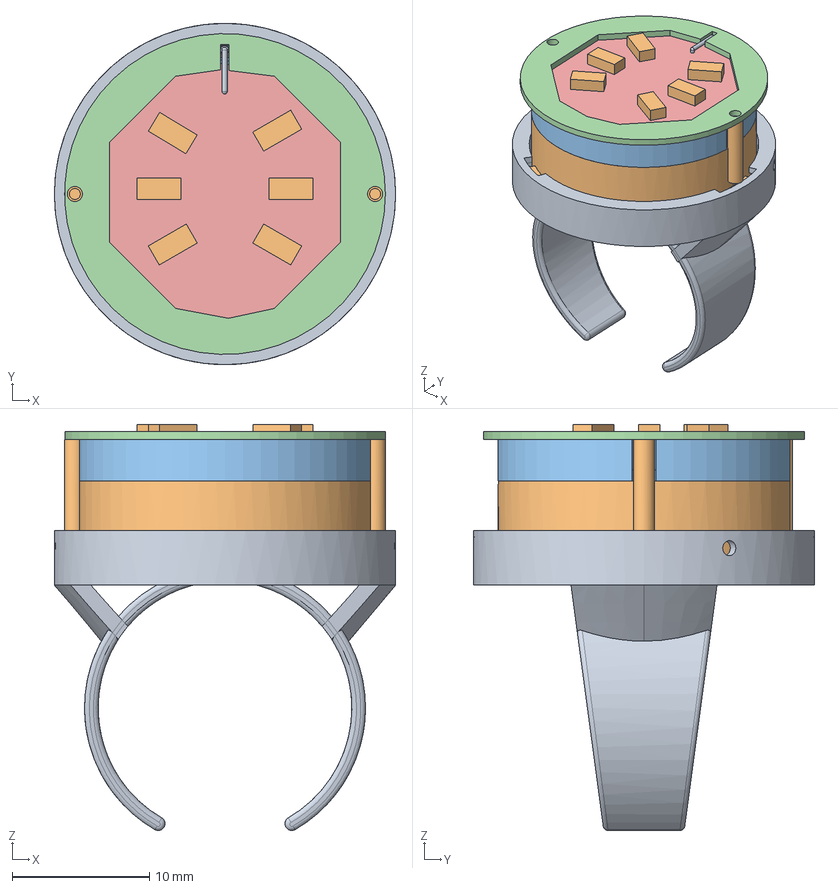
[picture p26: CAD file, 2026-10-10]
hardware/v2.0/ring_3d/generated/Lantern_Ring_v2.step
24.9 x 24.9 x 29.6 mm

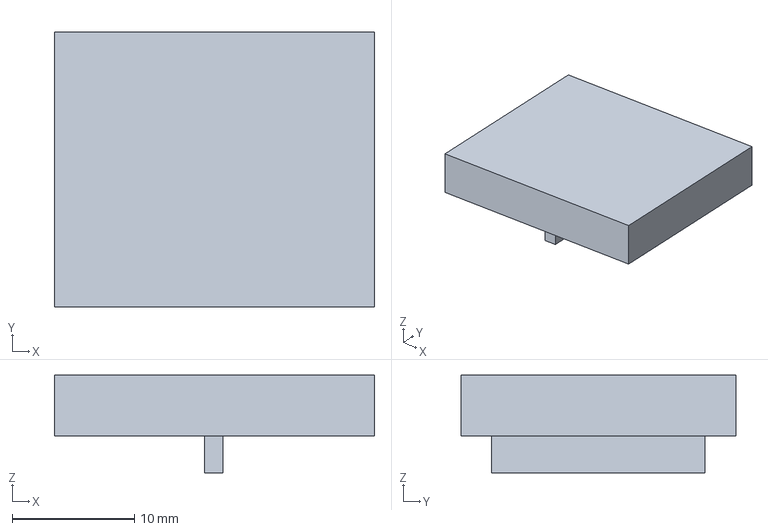
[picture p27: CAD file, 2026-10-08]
hardware/v2.0/ring_ir_prog_clip/generated/fit/Riser.step
26.2 x 22.5 x 8.00 mm

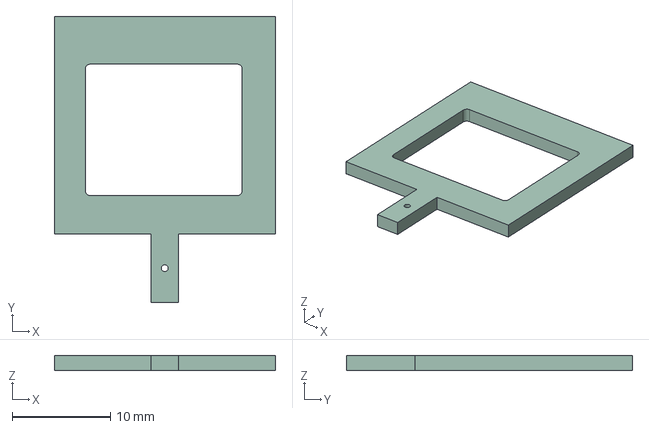
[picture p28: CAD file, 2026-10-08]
hardware/v2.0/ring_ir_prog_clip/generated/ring_ir_prog_anvil.step
22.5 x 29.2 x 1.51 mm

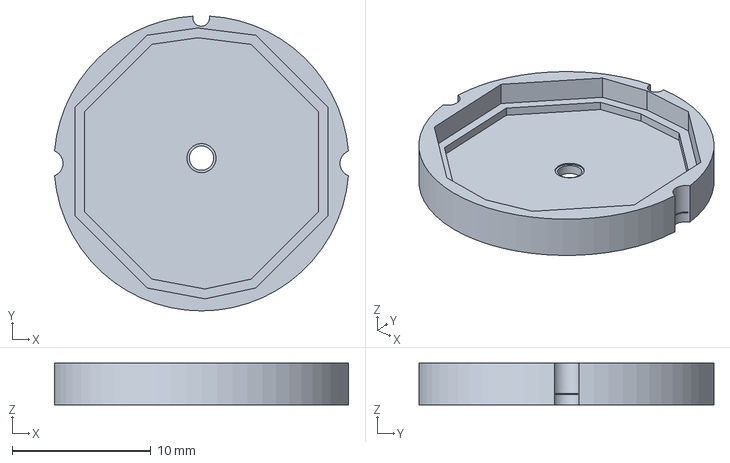
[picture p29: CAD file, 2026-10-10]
hardware/v2.0/ring_3d/generated/ContactDeck.step
21.2 x 21.3 x 3.02 mm

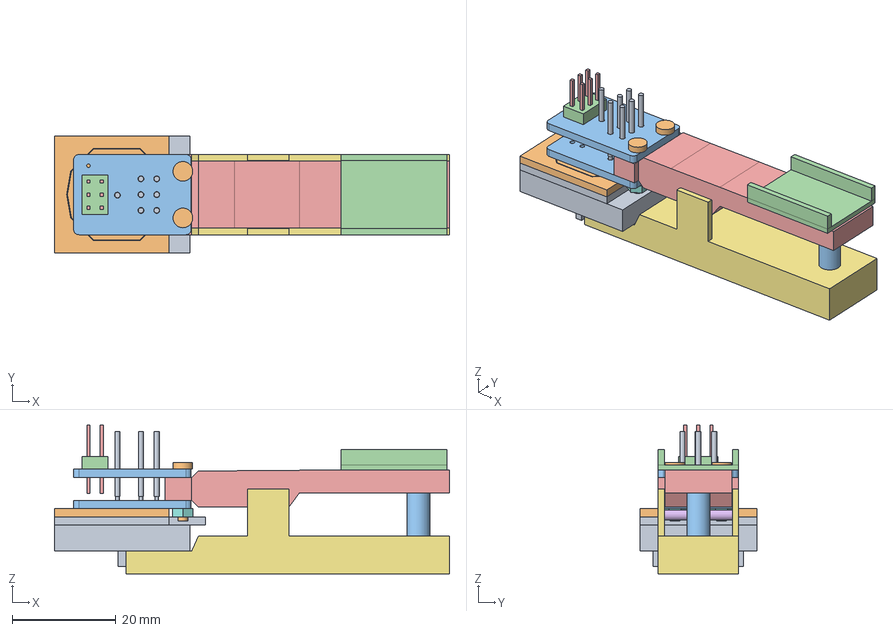
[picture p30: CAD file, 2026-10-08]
hardware/v2.0/ring_ir_prog_clip/generated/fit/clip_fit.step
76.3 x 22.5 x 28.7 mm

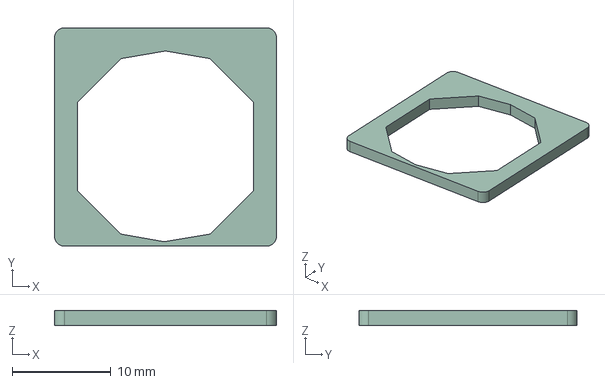
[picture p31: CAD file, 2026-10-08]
hardware/v2.0/ring_ir_prog_clip/generated/ring_ir_prog_fence.step
22.5 x 22.2 x 1.51 mm

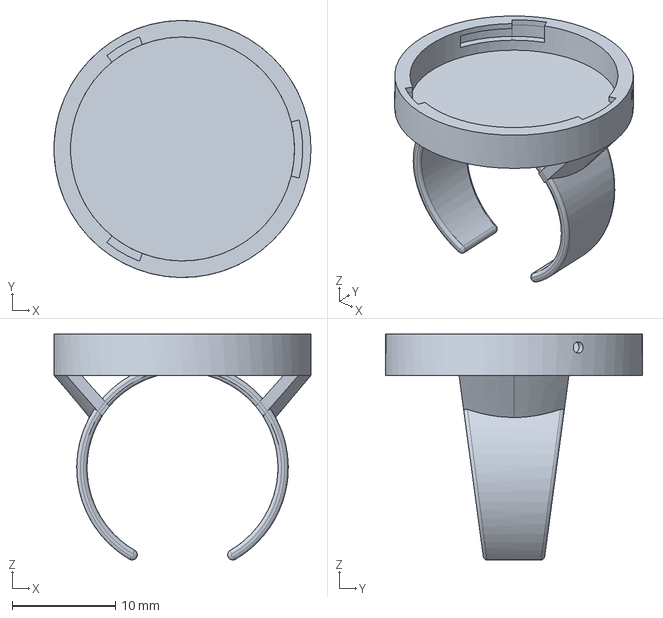
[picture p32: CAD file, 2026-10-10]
hardware/v2.0/ring_3d/generated/RingBase.step
24.9 x 24.9 x 21.9 mm

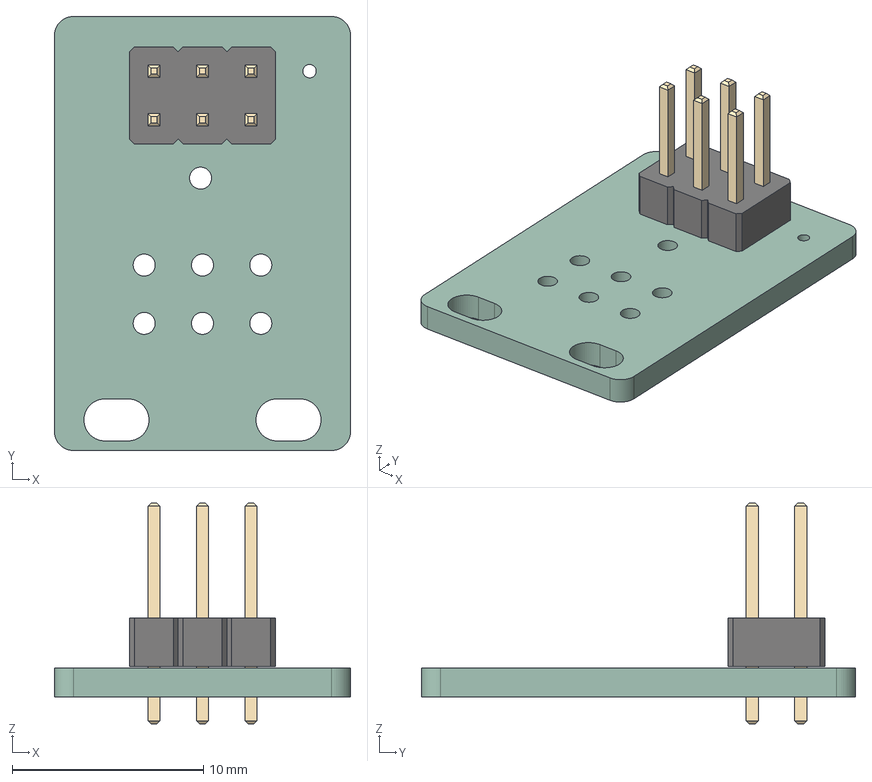
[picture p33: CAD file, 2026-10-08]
hardware/v2.0/ring_ir_prog_clip/generated/ring_ir_prog_probe.step
15.5 x 22.7 x 11.5 mm
PinHeader_2x03_P254mm_Vertical
ring_ir_prog_probe_PCB

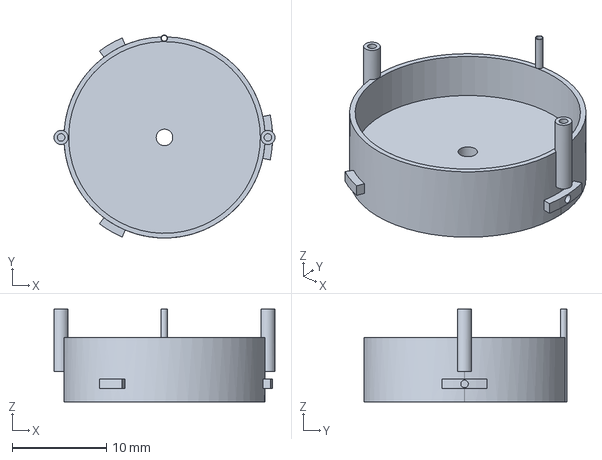
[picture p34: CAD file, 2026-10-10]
hardware/v2.0/ring_3d/generated/Carrier.step
23.4 x 21.5 x 9.82 mm

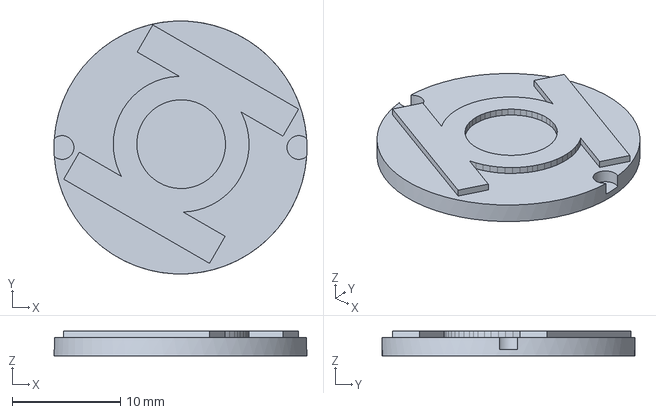
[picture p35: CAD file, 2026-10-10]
hardware/v2.0/ring_3d/generated/crowns/Crown_will.step
23.4 x 23.4 x 2.30 mm

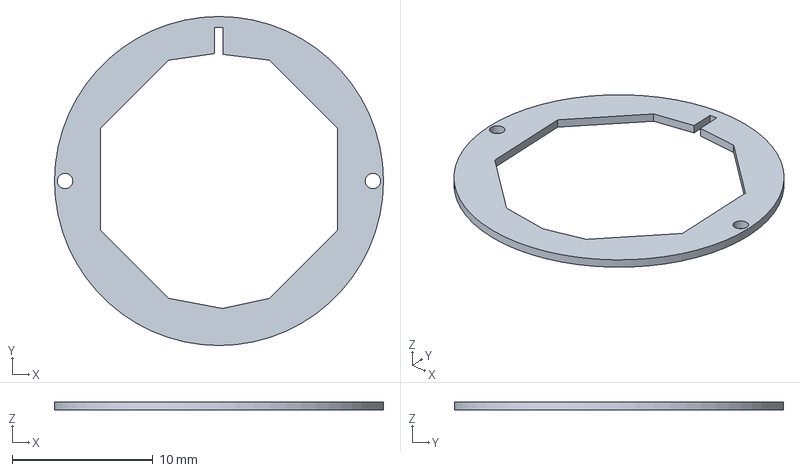
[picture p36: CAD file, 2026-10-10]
hardware/v2.0/ring_3d/generated/Bezel.step
23.4 x 23.4 x 0.6 mm

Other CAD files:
hardware/v2.0/ring_3d/generated/crowns/Crown_avarice.step
hardware/v2.0/ring_3d/generated/crowns/Crown_fear.step
hardware/v2.0/ring_3d/generated/crowns/Crown_love.step
hardware/v2.0/ring_3d/generated/crowns/Crown_compassion.step
hardware/v2.0/ring_3d/generated/crowns/Crown_hope.step
hardware/v2.0/ring_3d/generated/crowns/Crown_life.step
hardware/v1.0/ring_3d/38_solid.blend
hardware/v1.0/ring_3d/CR-2032 v1.step
hardware/v1.0/ring_3d/Lantern_Ring_Assembly-avarice_logo.stl
hardware/v1.0/ring_3d/Lantern_Ring_Assembly-bar38_38_bex.stl
hardware/v1.0/ring_3d/Lantern_Ring_Assembly-bar38_logo.stl
hardware/v1.0/ring_3d/Lantern_Ring_Assembly-bar38_logo_bex.stl
hardware/v1.0/ring_3d/Lantern_Ring_Assembly-bar_38_extrude_000.stl
hardware/v1.0/ring_3d/Lantern_Ring_Assembly-bar_38_extrude_001.stl
hardware/v1.0/ring_3d/Lantern_Ring_Assembly-empathy_logo.stl
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

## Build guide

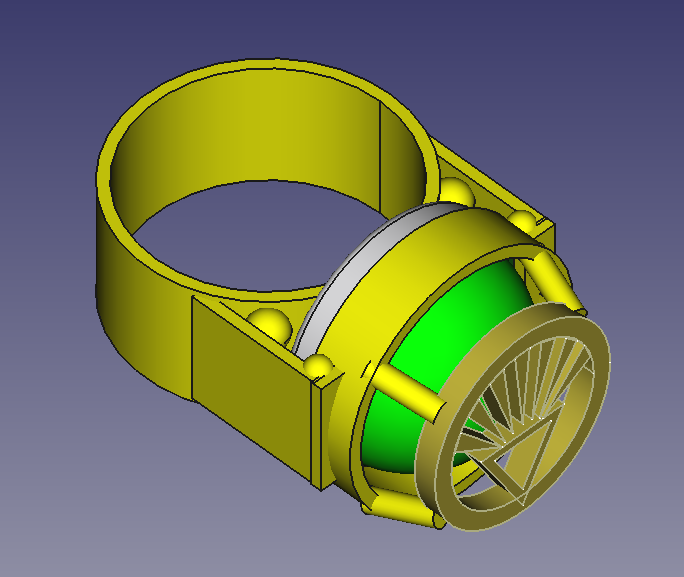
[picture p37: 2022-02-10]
docs/ring_assembly_bw.png

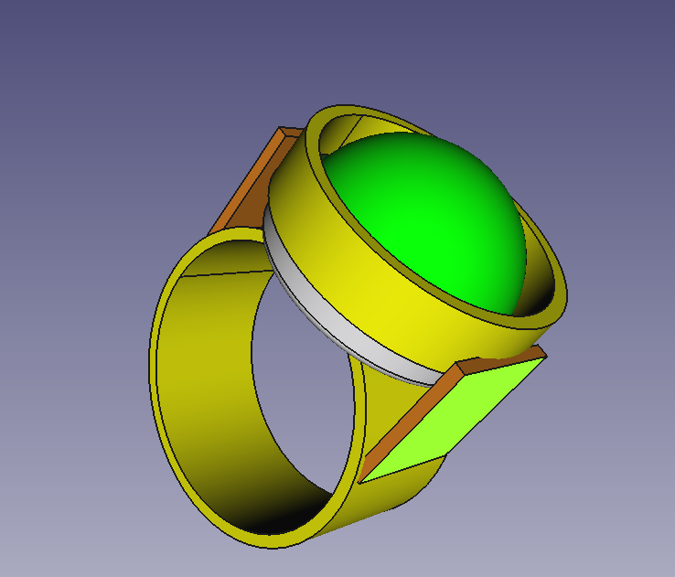
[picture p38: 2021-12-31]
docs/ring_assembly.png

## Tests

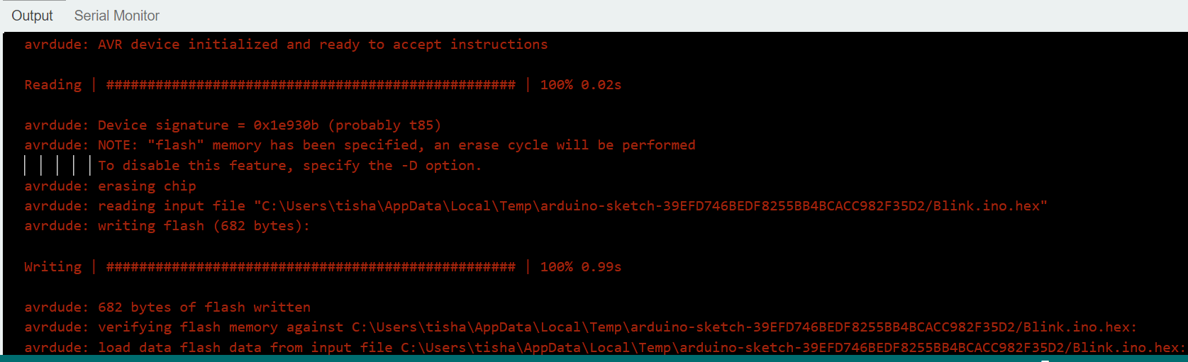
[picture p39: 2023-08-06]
docs/at85_verified.png

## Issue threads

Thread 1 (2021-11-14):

How I get one?

RichardScottOZ, 2021-11-14:
:)
I have a cheap jewellery thing and a few plastic varieties.

whatnick, 2022-01-28:
STL files are now available. I have successfully 3D printed prototypes and slotted in battery etc for fully working props. We should catch up and I can give you a plastic one to show off.

RichardScottOZ, 2022-01-28:
Sounds good!

Closed 2022-01-28.

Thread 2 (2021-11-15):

Ideas on physical/visual design

j0ono0, 2021-11-15:
Some visuals as previously discussed. whilst sketching it became apparent I have no strong idea of desired outcomes from a visual design perspective. So these are purely 'speculative dreaming'.
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

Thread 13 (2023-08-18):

Implement PCB with programmable colour LED

whatnick, 2023-08-18:
Use APA102 or WS2812 addressable LED's to have changing colours.

- [ ]  Change colours using some sort of physical tuner style interface
- [ ]  Implement schematic
- [ ]  Implement PCB
- [ ]  Assemble and test

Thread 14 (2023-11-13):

Activate ring on high acceleration

whatnick, 2023-11-13:
The ring is constantly on draining power, use a low power MEMS accelerometer to activate the ring on high acceleration. Using an analog output accelerometer can avoid use of a microcontroller and directly activate LED's via a Mosfet/BJT.

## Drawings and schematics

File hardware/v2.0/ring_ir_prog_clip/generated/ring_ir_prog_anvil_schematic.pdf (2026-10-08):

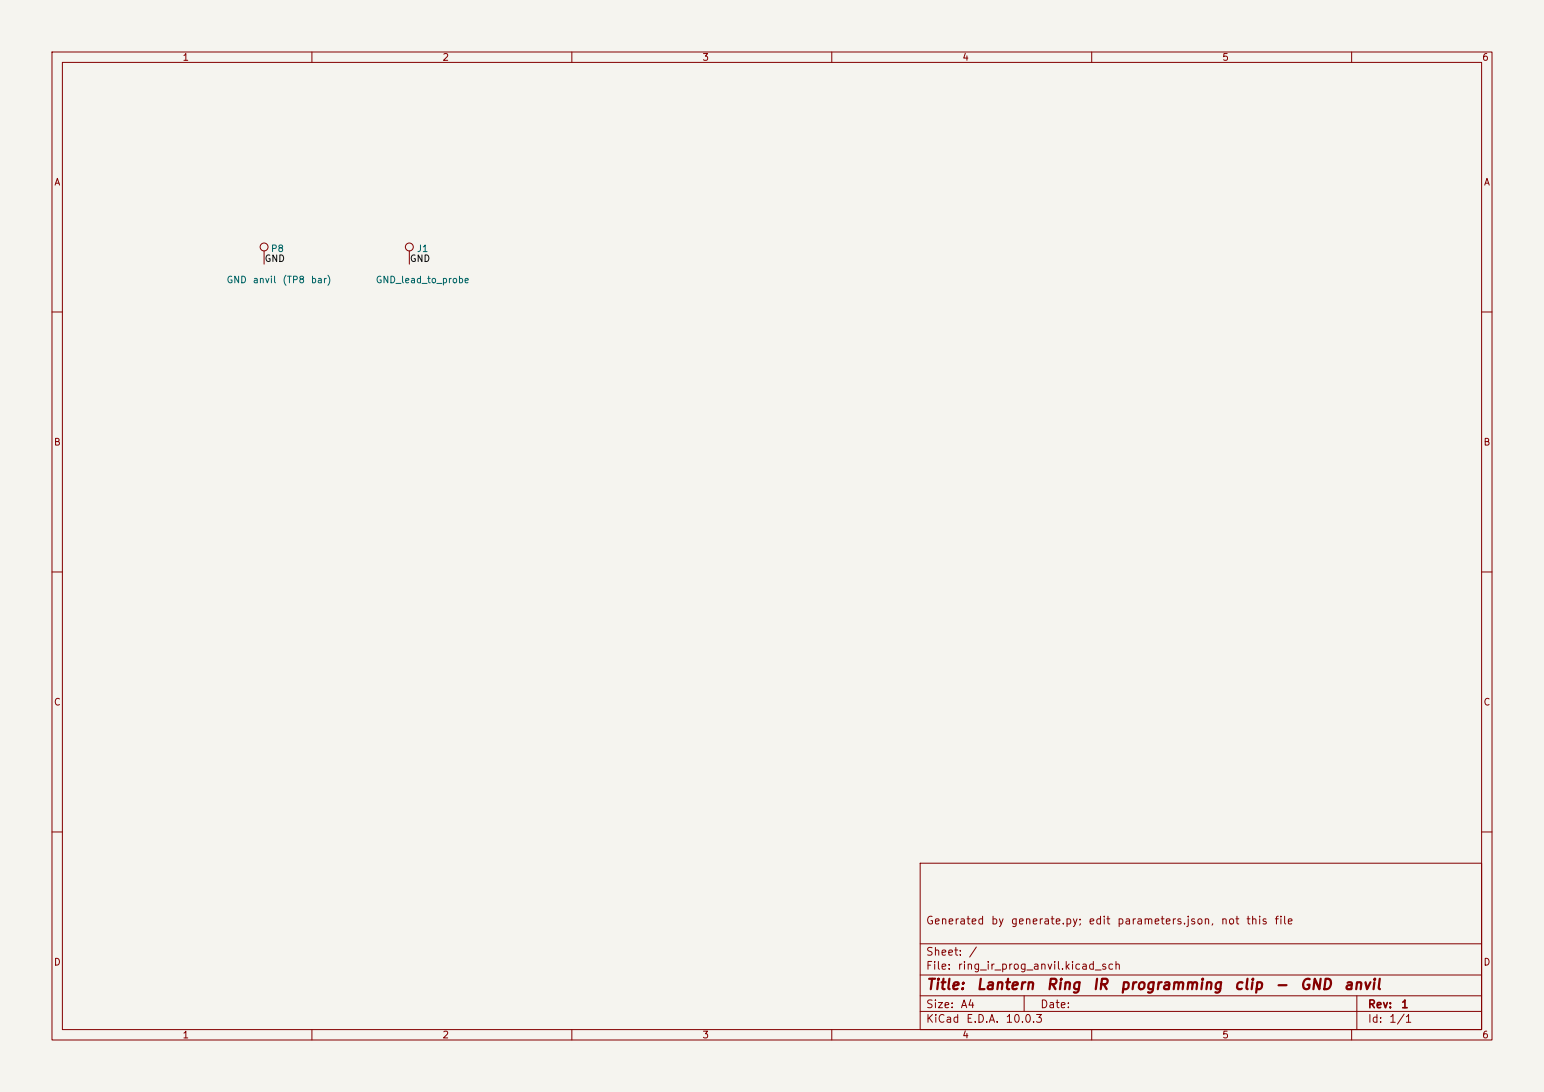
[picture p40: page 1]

Generated by generate.py; edit parameters.json, not this file

Sheet: /
File: ring_ir_prog_anvil.kicad_sch
Title: Lantern Ring IR programming clip - GND anvil

Size: A4 | Rev: 1
KiCad E.D.A. 10.0.3 | Id: 1/1

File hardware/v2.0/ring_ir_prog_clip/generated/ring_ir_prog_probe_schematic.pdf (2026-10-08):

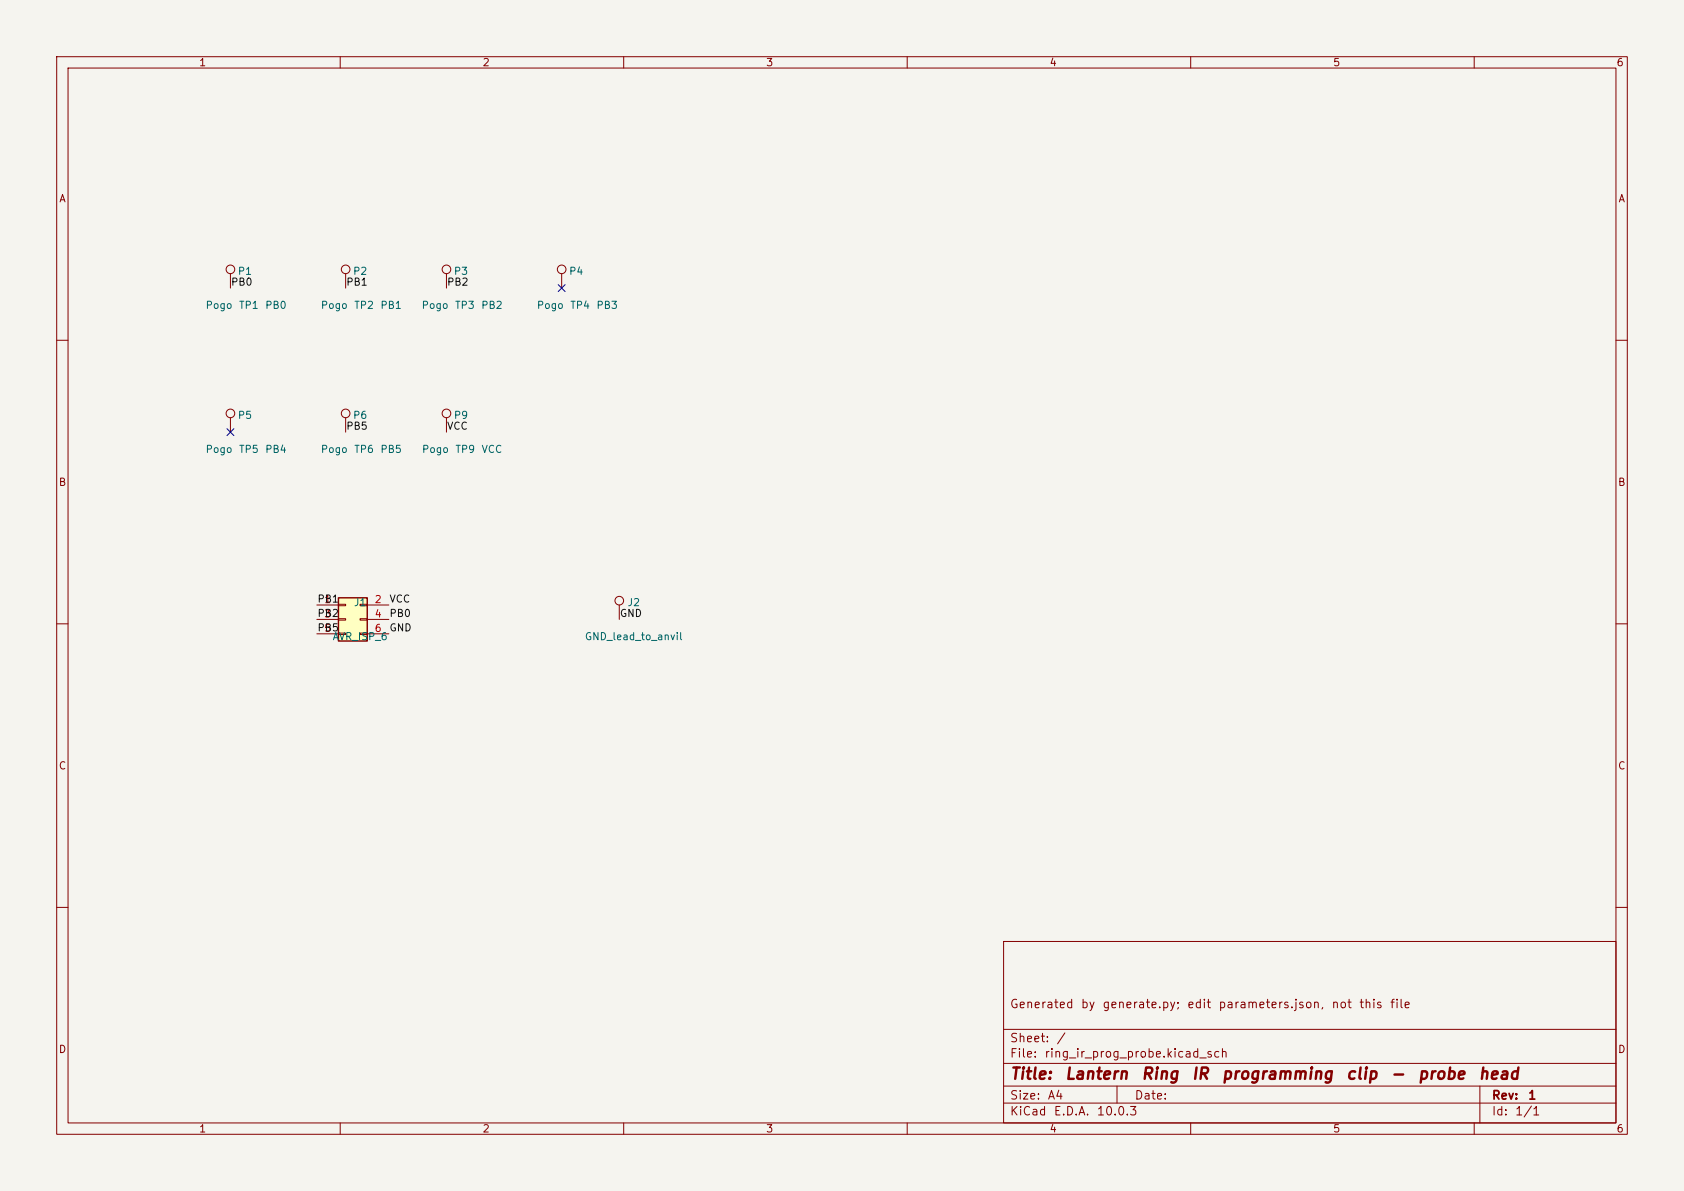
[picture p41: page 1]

Generated by generate.py; edit parameters.json, not this file

Sheet: /
File: ring_ir_prog_probe.kicad_sch
Title: Lantern Ring IR programming clip - probe head

Size: A4 | Rev: 1
KiCad E.D.A. 10.0.3 | Id: 1/1

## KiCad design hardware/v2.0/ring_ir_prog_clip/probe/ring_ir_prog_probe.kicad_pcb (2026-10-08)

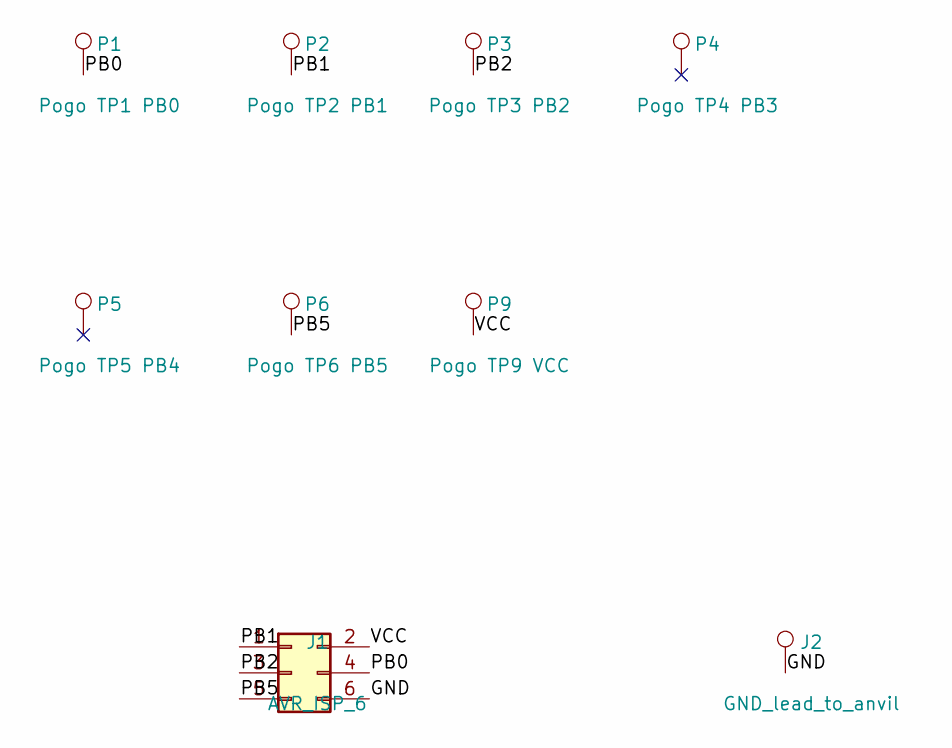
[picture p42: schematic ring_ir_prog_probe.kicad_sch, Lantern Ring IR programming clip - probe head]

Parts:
J1: AVR_ISP_6; PinHeader_2x03_P2.54mm_Vertical
J2: GND_lead_to_anvil; TestPoint_THTPad_D1.5mm_Drill0.7mm
P1: Pogo TP1 PB0; Pogo_P75_THT
P2: Pogo TP2 PB1; Pogo_P75_THT
P3: Pogo TP3 PB2; Pogo_P75_THT
P4: Pogo TP4 PB3; Pogo_P75_THT
P5: Pogo TP5 PB4; Pogo_P75_THT
P6: Pogo TP6 PB5; Pogo_P75_THT
P9: Pogo TP9 VCC; Pogo_P75_THT

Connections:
/GND: J1.6, J2.1
/PB0: J1.4, P1.1
/PB1: J1.1, P2.1
/PB2: J1.3, P3.1
/PB5: J1.5, P6.1
/VCC: J1.2, P9.1

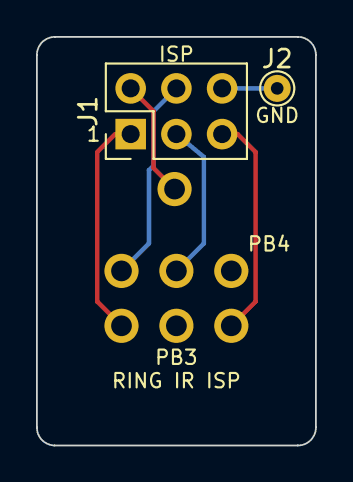
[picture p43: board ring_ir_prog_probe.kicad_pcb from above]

Board: 2 copper layers, 15.5 x 22.7 mm, 11 parts (0 on the bottom side), 6 nets.

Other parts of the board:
H1, H2: M2_Slot_Clip_Jaw

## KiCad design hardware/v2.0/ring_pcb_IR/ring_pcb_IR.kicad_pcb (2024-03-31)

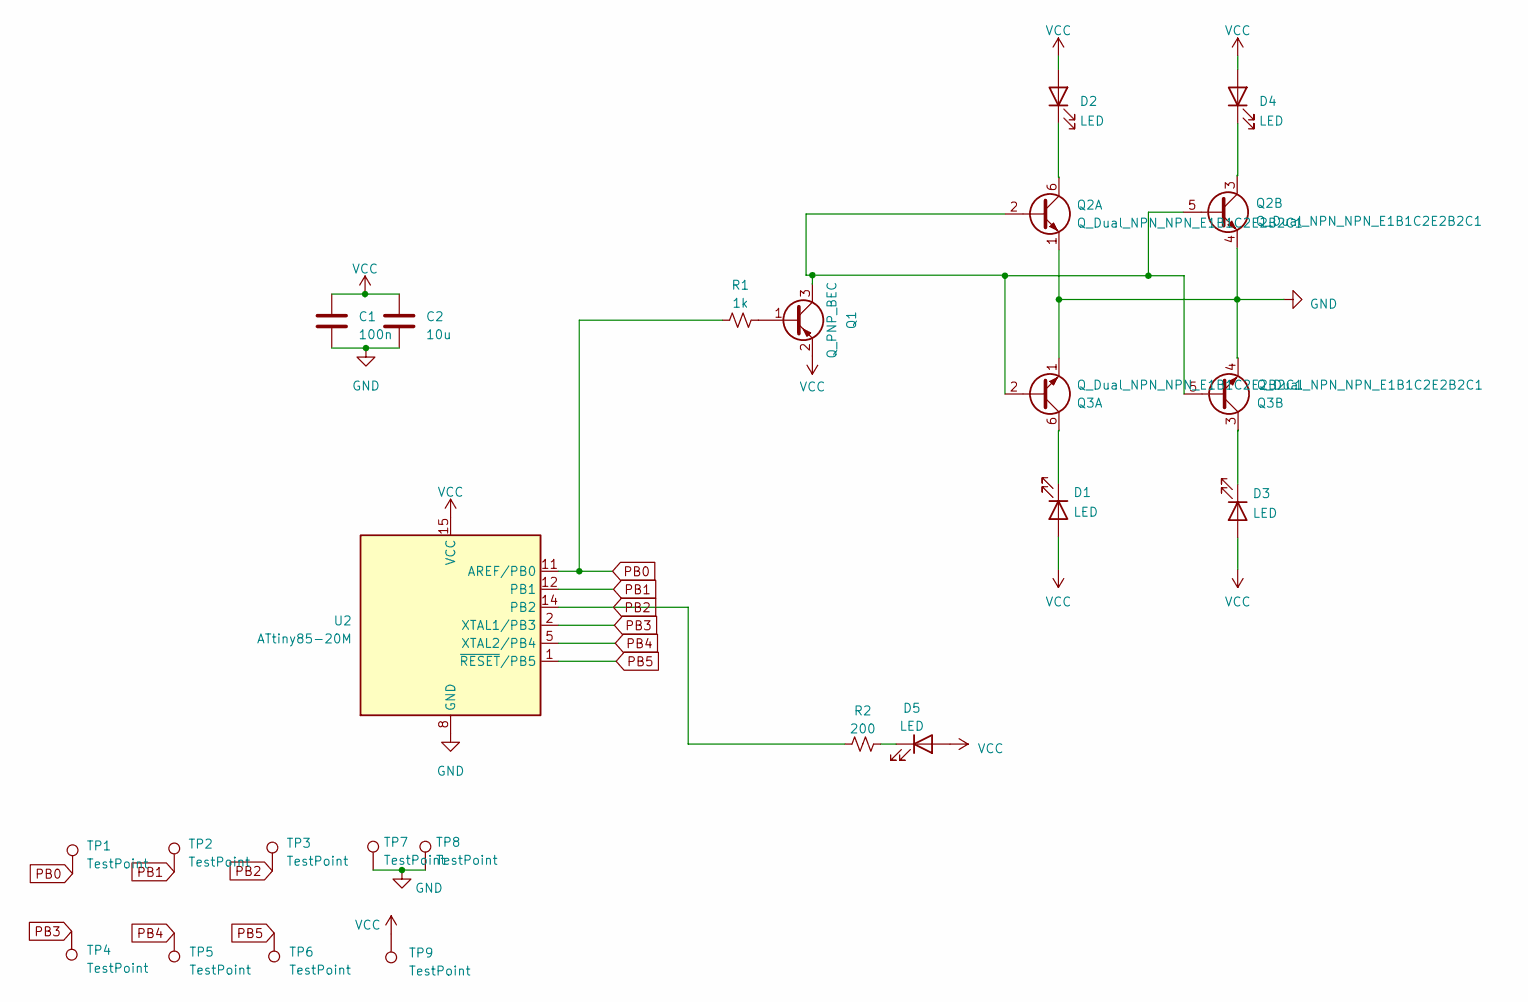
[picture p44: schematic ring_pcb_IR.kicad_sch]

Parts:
C1: 100n; C_0603_1608Metric; MPN C0603C104J4RACTU
C2: 10u; C_0603_1608Metric; MPN GRM188R61A106KE69J
D1, D2, D3, D4: LED; LED_0603_1608Metric; MPN 15406094BA500
D5: LED; LED_0603_1608Metric; MPN 150060RS75000
Q1: Q_PNP_BEC; SOT-23; MPN MMBTA55LT1G
Q2, Q3: Q_Dual_NPN_NPN_E1B1C2E2B2C1; SOT-363_SC-70-6; MPN BC847BS,115
R1: 1k; R_0603_1608Metric; MPN RT0603FRE101KL
R2: 200; R_0603_1608Metric; MPN RT0603BRD07210RL
TP1, TP2, TP3, TP4, TP5, TP6, TP7, TP8, TP9: TestPoint; TestPoint_Pad_1.0x1.0mm; MPN DNP
U2: ATtiny85-20M; QFN-20-1EP_4x4mm_P0.5mm_EP2.6x2.6mm; MPN ATTINY85-20MU

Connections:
GND: C1.2, C2.2, Q2.1 (E1), Q2.4 (E2), Q3.1 (E1), Q3.4 (E2), TP7.1, TP8.1, U2.8 (GND), U2.21 (GND)
unnamed: D1.1 (K), Q3.6 (C1)
unnamed: D2.1 (K), Q2.6 (C1)
unnamed: D3.1 (K), Q3.3 (C2)
unnamed: D4.1 (K), Q2.3 (C2)
unnamed: D5.1 (K), R2.1
unnamed: Q1.1 (B), R1.2
unnamed: Q1.3 (C), Q2.2 (B1), Q2.5 (B2), Q3.2 (B1), Q3.5 (B2)
PB0: R1.1, TP1.1, U2.11 (AREF/PB0)
PB1: TP2.1, U2.12 (PB1)
PB2: R2.2, TP3.1, U2.14 (PB2)
PB3: TP4.1, U2.2 (XTAL1/PB3)
PB4: TP5.1, U2.5 (XTAL2/PB4)
PB5: TP6.1, U2.1 (~RESET/PB5)
VCC: C1.1, C2.1, D1.2 (A), D2.2 (A), D3.2 (A), D4.2 (A), D5.2 (A), Q1.2 (E), TP9.1, U2.15 (VCC)

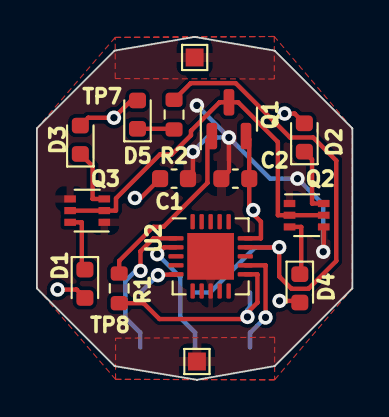
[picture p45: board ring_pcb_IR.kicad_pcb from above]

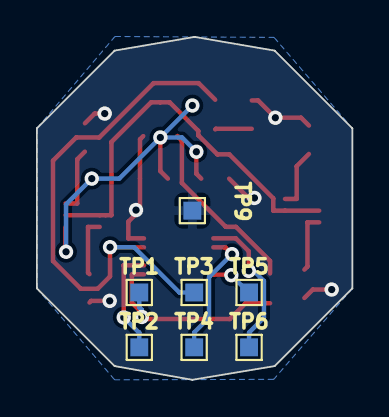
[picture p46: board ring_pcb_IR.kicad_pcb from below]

Board: 2 copper layers, 17.5 x 19.1 mm, 22 parts (7 on the bottom side), 15 nets.

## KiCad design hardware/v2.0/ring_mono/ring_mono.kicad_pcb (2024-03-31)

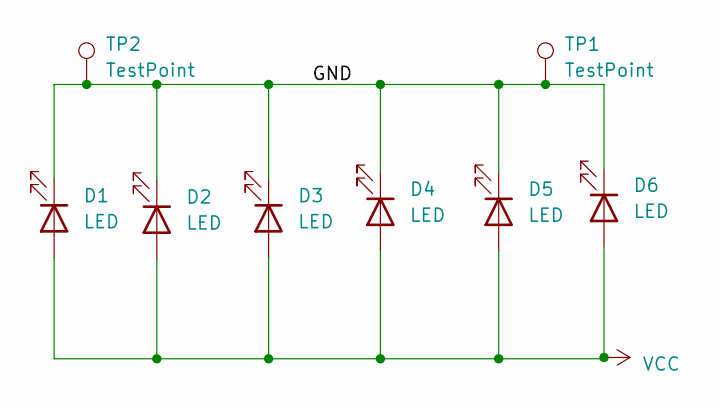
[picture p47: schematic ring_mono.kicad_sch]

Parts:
D1, D2, D3, D4, D5, D6: LED; LED_1206_3216Metric
TP1, TP2: TestPoint; TestPoint_Pad_1.5x1.5mm

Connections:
/GND: D1.1 (K), D2.1 (K), D3.1 (K), D4.1 (K), D5.1 (K), D6.1 (K), TP1.1, TP2.1
VCC: D1.2 (A), D2.2 (A), D3.2 (A), D4.2 (A), D5.2 (A), D6.2 (A)

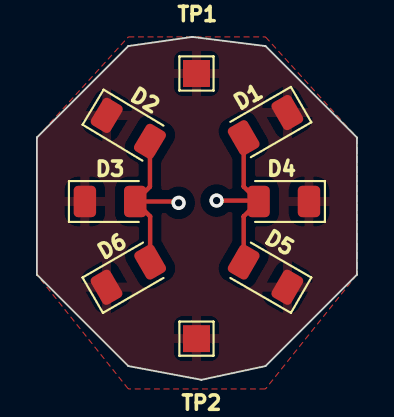
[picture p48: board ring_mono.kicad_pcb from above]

Board: 2 copper layers, 17.8 x 19.0 mm, 8 parts (0 on the bottom side), 2 nets.

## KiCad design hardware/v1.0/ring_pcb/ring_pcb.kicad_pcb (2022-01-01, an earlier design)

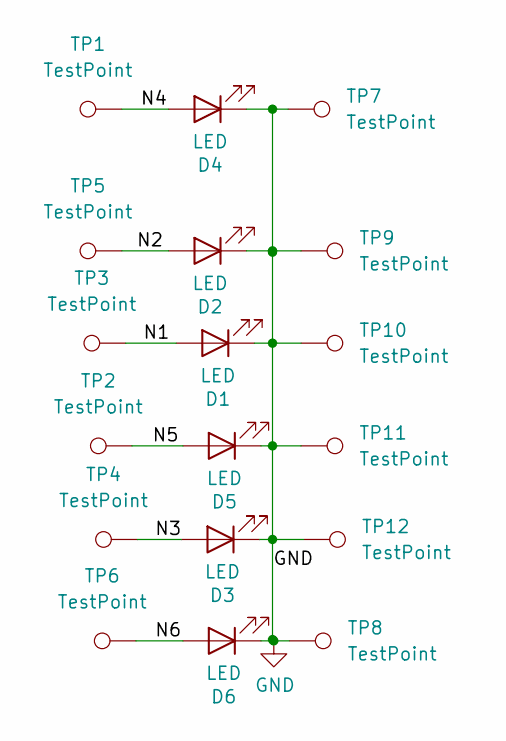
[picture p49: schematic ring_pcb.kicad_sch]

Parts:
D1, D2, D3, D4, D5, D6: LED; LED_1206_3216Metric
TP1, TP2, TP3, TP4, TP5, TP6, TP7, TP8, TP9, TP10, TP11, TP12: TestPoint; TestPoint_Pad_1.5x1.5mm

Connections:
/N1: D1.2 (A), TP3.1
/N2: D2.2 (A), TP5.1
/N3: D3.2 (A), TP4.1
/N4: D4.2 (A), TP1.1
/N5: D5.2 (A), TP2.1
/N6: D6.2 (A), TP6.1
GND: D1.1 (K), D2.1 (K), D3.1 (K), D4.1 (K), D5.1 (K), D6.1 (K), TP7.1, TP8.1, TP9.1, TP10.1, TP11.1, TP12.1

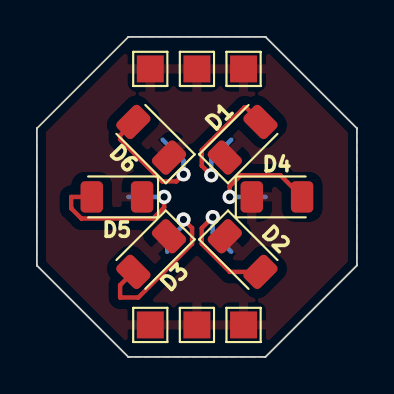
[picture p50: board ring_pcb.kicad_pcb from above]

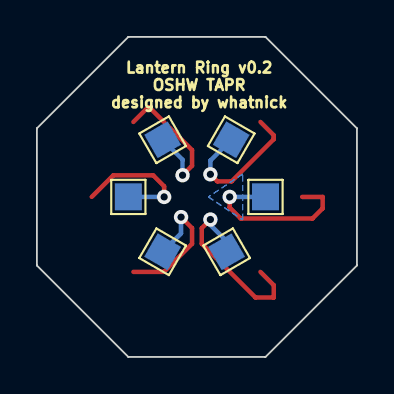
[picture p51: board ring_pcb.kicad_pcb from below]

Board: 2 copper layers, 17.8 x 17.8 mm, 18 parts (6 on the bottom side), 7 nets.

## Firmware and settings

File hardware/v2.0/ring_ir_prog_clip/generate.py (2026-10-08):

"""Generate the Lantern Ring IR programming-clip PCBs.

Run with KiCad 10's bundled Python from the repository root:

    & 'C:\\Program Files\\KiCad\\10.0\\bin\\python.exe' hardware\\v2.0\\ring_ir_prog_clip\\generate.py

The ring_pcb_IR board is the only geometry source.  Pad positions, nets, the
front component envelope and the exposed front GND bar are read from it, so
the clip follows the target board instead of a hand-copied pattern.

Clip frame: (u, v) in mm, viewed from the probe side, looking at the target's
rear test pads.  u = -(x - TP3.x) mirrors KiCad X, v = y - TP3.y.
"""

import hashlib
import json
import math
import os
import re
import sys
import uuid

import pcbnew

HERE = os.path.dirname(os.path.abspath(__file__))
KICAD_SHARE = os.environ.get("KICAD_SHARE", r"C:\Program Files\KiCad\10.0\share\kicad")
LIB_NAME = "ring_ir_prog_clip"
LIB_DIR = os.path.join(HERE, LIB_NAME + ".pretty")
ORIGIN = (150.0, 100.0)
NS = uuid.UUID("5d1d6f0e-6c4b-4e0a-9d6e-6c616e74726e")


def uid(*parts):
    return str(uuid.uuid5(NS, "/".join(str(p) for p in parts)))


def mm(v):
    return pcbnew.ToMM(v)


def pt(u, v):
    return pcbnew.VECTOR2I(pcbnew.FromMM(ORIGIN[0] + u), pcbnew.FromMM(ORIGIN[1] + v))


def sha256(path):
    with open(path, "rb") as handle:
        return hashlib.sha256(handle.read().replace(b"\r\n", b"\n")).hexdigest()


def load_parameters():
    with open(os.path.join(HERE, "parameters.json"), encoding="utf-8") as handle:
        return json.load(handle)


# ---------------------------------------------------------------- target board

def read_target(params):
    path = os.path.normpath(os.path.join(HERE, params["dut"]["board"]))
    board = pcbnew.LoadBoard(path)
    pads = {}
    courtyards = []
    for fp in board.GetFootprints():
        ref = fp.GetReference()
        if ref.startswith("TP"):
            pad = fp.Pads()[0]
            pos = pad.GetPosition()
            size = pad.GetSize()
            pads[ref] = {
                "x": mm(pos.x), "y": mm(pos.y), "net": pad.GetNetname(),
                "layer": board.GetLayerName(fp.GetLayer()),
                "size": [mm(size.x), mm(size.y)],
            }
        elif fp.GetLayer() == pcbnew.F_Cu:
            box = fp.GetCourtyard(pcbnew.F_CrtYd).BBox()
            courtyards.append((ref, mm(box.GetLeft()), mm(box.GetTop()),
                               mm(box.GetRight()), mm(box.GetBottom()), fp.GetFPIDAsString()))
    outline = None
    for drawing in board.GetDrawings():
        if drawing.GetLayer() == pcbnew.Edge_Cuts and drawing.GetShape() == pcbnew.SHAPE_T_POLY:
            outline = [(mm(p.x), mm(p.y)) for p in drawing.GetPolyPoints()]
    if outline is None:
        raise SystemExit("target outline polygon not found")
    gnd = params["dut"]["ground_test_point"]
    gx, gy = pads[gnd]["x"], pads[gnd]["y"]
    bar = None
    for zone in board.Zones():
        layers = [board.GetLayerName(l) for l in zone.GetLayerSet().Seq()]
        box = zone.GetBoundingBox()
        rect = (mm(box.GetLeft()), mm(box.GetTop()), mm(box.GetRight()), mm(box.GetBottom()))
        if (layers == ["F.Cu"] and zone.GetNetname() == "GND" and rect[0] <= gx <= rect[2]
                and rect[1] <= gy <= rect[3] and rect[2] - rect[0] < 12):
            bar = rect
    if bar is None:
        raise SystemExit("front GND bar under %s not found" % gnd)
    thickness = mm(board.GetDesignSettings().GetBoardThickness())
    return {"path": path, "pads": pads, "courtyards": courtyards,
            "outline": outline, "gnd_bar": bar, "thickness": thickness}


def to_uv(target, params, x, y):
    o = target["pads"][params["dut"]["origin_test_point"]]
    return (-(x - o["x"]), y - o["y"])


def check_target(target, params):
    errors = []
    for ref, net in params["dut"]["expected_nets"].items():
        pad = target["pads"].get(ref)
        if pad is None:
            errors.append("%s missing" % ref)
        elif pad["net"] != net:
            errors.append("%s net %s != %s" % (ref, pad["net"], net))
    for ref in params["dut"]["probe_test_points"]:
        if target["pads"][ref]["layer"] != "B.Cu":
            errors.append("%s is not on the rear" % ref)
    if target["pads"][params["dut"]["ground_test_point"]]["layer"] != "F.Cu":
        errors.append("ground test point is not on the front")
    if errors:
        raise SystemExit("target board changed: " + "; ".join(errors))


# ------------------------------------------------------------- local footprints
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

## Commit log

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2021-12-31 Update pcb to v0.2 for new mounting plan
    [ring_pcb.kicad_pcb, ring_pcb.kicad_sch]
2021-12-31 More vias and keepouts
    [ring_pcb.kicad_pcb, ring_pcb.kicad_sch]
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2022-01-01 New PCB and Gerbers
    [ring_pcb-B_Cu.gbl, ring_pcb-B_Mask.gbs, ring_pcb-B_Paste.gbp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]
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2022-01-22 Add fear logo supports
    [Lantern_Ring_Assembly-fear_logo.stl, Lantern_Ring_Assembly.FCStd]
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2022-02-03 Add more elements to resurrection
    [Lantern_Ring_Assembly.FCStd]
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2022-02-14 Add star sapphire logo
    [Lantern_Ring_Assembly-love_logo.stl, Lantern_Ring_Assembly.FCStd]
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2022-02-19 Rename empathy logo for consistency
    [Lantern_Ring_Assembly-empathy_logo.stl]
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2022-03-12 Started on custom logo top
    [Lantern_Ring_Assembly.FCStd]
2022-03-12 Badly extruded version of logo pending education on shrink wrapping
    [Lantern_Ring_Assembly-bar38_logo.stl, Lantern_Ring_Assembly.FCStd]
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2022-03-12 Bar 38 logo completed
    [38_solid.blend, Lantern_Ring_Assembly-bar38_38_bex.stl, Lantern_Ring_Assembly-bar38_logo.stl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]
2022-03-14 Start on MTG mana logos
    [Lantern_Ring_Assembly-mtg_black_logo.stl, Lantern_Ring_Assembly-mtg_black_logo_bex.stl, Lantern_Ring_Assembly.FCStd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]
2022-03-19 Added red logo sketch
    [Lantern_Ring_Assembly.FCStd]
2022-03-19 Sketch white/sun logo for MTG
    [Lantern_Ring_Assembly.FCStd]
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2022-03-20 Complete all MTG traces, add blue logo STL
    [Lantern_Ring_Assembly-mtg_blue_logo.stl, Lantern_Ring_Assembly.FCStd]
2022-03-30 Start on Fengshui cover
    [Lantern_Ring_Assembly.FCStd]
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2022-04-23 Add collar for slotting rage logo
    [Lantern_Ring_Assembly-rage_logo.stl, Lantern_Ring_Assembly.FCStd]
2022-04-30 Add collars to all logos
    [Lantern_Ring_Assembly-avarice_logo.stl, Lantern_Ring_Assembly-empathy_logo.stl, Lantern_Ring_Assembly-fear_logo.stl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]
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2022-06-01 Add size 165 stl
    [Lantern_Ring_Assembly-ring_body_165.stl]
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2022-08-12 More work on compass
    [Lantern_Ring_Assembly-feng_shui_compass.stl, Lantern_Ring_Assembly-mtg_black_logo.stl, Lantern_Ring_Assembly-mtg_blue_logo.stl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]
2022-08-27 Add STL for will logo with press fit balls
    [Lantern_Ring_Assembly-will_logo.stl, Lantern_Ring_Assembly.FCStd]
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2022-09-03 Create 185 size body
    [Lantern_Ring_Assembly-ring_body_185.stl, Lantern_Ring_Assembly.FCStd]
2022-09-10 Add remeshed size 185
    [Lantern_Ring_Assembly-ring_body_185.stl]
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2022-10-01 Add red and black STL's
    [Lantern_Ring_Assembly-mtg_black_logo.stl, Lantern_Ring_Assembly-mtg_red_logo.stl, Lantern_Ring_Assembly.FCStd]
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2022-11-13 Start on InfraRed ring design
    [ring_pcb_IR.kicad_pcb, ring_pcb_IR.kicad_sch]
2022-11-19 Start wiring up LED driver
    [ring_pcb_IR.kicad_pcb, ring_pcb_IR.kicad_sch]
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2023-03-18 Add more wiring for LED and power pads
    [ring_pcb_IR.kicad_pcb, ring_pcb_IR.kicad_sch]
2023-04-30 Start on firmware and ring mods
    [Lantern_Ring_Assembly-will_logo.stl, Lantern_Ring_Assembly.FCStd]
2023-08-06 Add simple monocolour PCB
    [ring_mono-B_Cu.gbr, ring_mono-B_Mask.gbr, ring_mono-B_Paste.gbr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]
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2023-08-12 Fix routing, squash unrouted
    [ring_pcb_IR.kicad_pcb]
2023-08-18 Start implementing controlled APA102
    [ring_pcb_dotstar.kicad_pcb, ring_pcb_dotstar.kicad_sch]
2023-09-10 Make mono PCB smaller
    [ring_mono-B_Cu.gbr, ring_mono-B_Mask.gbr, ring_mono-B_Paste.gbr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]
2023-09-10 Add pad at the bottom
    [ring_mono-B_Cu.gbr, ring_mono-B_Mask.gbr, ring_mono-B_Paste.gbr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]
2023-11-23 Send PCB to be made
    [ring_pcb_IR-B_Cu.gbr, ring_pcb_IR-B_Mask.gbr, ring_pcb_IR-B_Paste.gbr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]
2023-11-24 Add collector connection for PNP
    [ring_pcb_IR-B_Cu.gbr, ring_pcb_IR-B_Mask.gbr, ring_pcb_IR-B_Paste.gbr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]
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2026-10-06 Add FreeCAD v2 bayonet cassette and pogo battery interface
    Add parametric native CAD, validated STEP/STL exports, assembly and prototype safety documentation, portable and native-edit regression tests, and repository Copilot instructions and reconstruction s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
    [Bezel.step, Bezel.stl, Carrier.step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]
2026-10-06 Add contact and insulated metal-body visual roadmap
    Include progressive local FreeCAD concepts, pressure-contact and isolation diagrams, Nano Banana prompts and an offline-tested image API client. Document missing image authentication explicitly and preserve the validated manufacturing CAD.
2026-10-06 Resize v2 ring using measured legacy proportions
    Replace long axial contacts with compact 0965 SMT pogo pins, eliminate the positive lead, restore the legacy band dimensions, and regenerate CAD and same-scale comparison renders.
    [Bezel.step, Bezel.stl, Carrier.step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]
2026-10-07 Lower crown and add open elastic-fit ring band
    Nest the finger arc into the insulated crown underside, shorten the contact stack and bezel, and replace the closed loop with rounded PA12 spring arms. Regenerate native CAD, STEP/STL exports, previews, measured comparisons and the unqualified constant-curvature fit study.
    [Bezel.step, Bezel.stl, Carrier.step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]
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2026-10-07 Add hollow 40-degree shoulder braces and tapered comfort-fit band
    Conical 1 mm shoulder walls brace the crown overhang onto the open band like the legacy side plates, with hollow pockets. The shank tapers 11->6 mm with 0.35 mm comfort-fit edges (-2.5% RingBase volu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
    [Bezel.step, Carrier.step, ContactDeck.step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]
2026-10-07 Add pogo pin comparison and tolerance screen
2026-10-07 Add generated pogo-pin ISP clip PCBs for ring_pcb_IR
    KiCad 10 generator derives probe, anvil and fence boards from the IR ring's rear test pads (3.05 mm grid plus central VCC) for an Adafruit 5434-style DIY pogo clip kit. Standard AVR ISP-6 header, fro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
    [ring_ir_prog_anvil-B_Cu.gbl, ring_ir_prog_anvil-B_Mask.gbs, ring_ir_prog_anvil-B_Silkscreen.gbo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]
2026-10-08 IR prog clip: estimated clip dimensions and FreeCAD virtual fit check
    [Riser.step, Riser.stl, clip_fit.FCStd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]
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2026-10-09 Add low-profile Lantern Corps crowns for the v2 top piece
    Replace the 6.5 mm v1 emblem with crowns.py: the validated bezel plus an
    LED-clearance skirt, 0.4 mm diffuser lens and 0.6 mm logo relief, 2.3 mm
    above the PCB. Logos for all eight corps are traced from the v1 FCStd into
    tool-neutral logos.json/SVG. Adds crowns.json validation, test_crowns.py and
    a CI step; the animation now uses the Will crown and renders a corps lineup.
    [Crown_avarice.step, Crown_avarice.stl, Crown_compassion.step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]
2026-10-09 Add Lantern Corps crown-swap animation and hero still
    corps_swap.py (Blender 5) swaps each corps crown on the assembled ring on a
    brushed-steel surface, relighting the LEDs in the corps colour with a caption,
    and renders a hero still of all eight rings on their side, caps to camera.
    render_corps.ps1 renders and encodes them; animate.py main is now import-safe.
2026-10-10 Extend carrier pillars to seat on ring base
    Regenerate FreeCAD exports, crown artifacts, previews, and Blender animations for the updated carrier geometry.
    [Bezel.step, Carrier.step, Carrier.stl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]
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2026-10-13 Avoid overlapping plane vias in ground-first router helper
2026-10-14 Redesign ring 3D parts for 1 mm minimum printed walls (Elecrow DFM)
    Add numpy STL wall-thickness checker (printcheck.py) with tests and CI gate,
    rework cassette and crowns, regenerate STL/STEP/renders and docs.
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2026-10-28 Use lower-cost lead-free HASL for purple clip PCB quotes
    Replace only the three clip jobs, update uploaded notes and SHA256-verified receipt, and document contact-flatness limitations. Clip subtotal USD68.89; no checkout or payment.
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
